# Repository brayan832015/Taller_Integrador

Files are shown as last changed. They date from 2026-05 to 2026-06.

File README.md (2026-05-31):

# EL5610 Integrative Workshop  
## Siwa Microcontroller Test and Interconnection Platform

This repository contains the development of the project for the **EL5610 Integrative Workshop** course at the School of Electronic Engineering, Instituto Tecnológico de Costa Rica.

The project consists of designing and developing a **test and interconnection platform for the Siwa microcontroller**, including schematic design, PCB layout, fabrication preparation, assembly, validation, and technical documentation.

## Development Methodology

This project is managed using the **Scrum Agile methodology**.

### Workflow includes:

- Product Backlog definition using GitHub Issues  
- Sprint planning and task prioritization  
- Iterative development cycles (Sprints)  
- Code/design reviews  
- Continuous progress tracking through GitHub Projects  

Version control is handled through feature branches and structured merges into the main branch.

---

## Repository Structure

```
/docs            → Technical documentation: Components datasheet and reports  
/pcb             → Schematic and PCB layout files  
```

---

## Roles and Responsibilities

### Brayan Barquero Madrigal – Project Owner
- Define and prioritize tasks in the Product Backlog.
- Ensure the board is properly updated (tasks moved to the correct columns).
- Review Pull Requests and approve or request changes.
- Ensure deliverables meet the acceptance criteria before moving them to **Done**.
- Take tasks from the Sprint Backlog and contribute technically to the project.
- Work on dedicated feature branches.
  
### Jeffrey Salas Quiel – Scrum Master
- Decide what enters each sprint.
- Lead the Daily Stand-Up (DSU) meetings.
- Identify blockers and help resolve them.
- Verify that each task has a clear description and an assigned responsible member.
- Take tasks from the Sprint Backlog and contribute technically to the project.
- Work on dedicated feature branches and create Pull Requests when tasks are completed.

### Priscilla Campos Zamora & Fiorela Chavarria Castrillo – Team Members
- Take tasks from the Sprint Backlog and move them to **In Progress**.
- Work on dedicated feature branches.
- Make clear commits and create a Pull Request when finished.
- Move tasks to **Review/Testing**, and then to **Done** once approved.
- Report blockers during meetings.

---

## Workflow

Product Backlog → Sprint Backlog → In Progress → Review/Testing → Done

---

## Tools & Technologies

- PCB CAD software (Altium Designer)  
- GitHub and Altium 365 for version control  
- Agile Scrum methodology  
- Laboratory validation equipment

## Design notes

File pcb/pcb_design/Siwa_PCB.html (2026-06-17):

Altium customize

# Board Information Report

Date: | | 6/15/2026
Time: | | 3:58:45 PM
Elapsed Time: | | 00:00:00
Filename: | | C:\Users\fchav\OneDrive - Estudiantes ITCR\SEMESTRE I 2026\TALLER INTEGRADOR\GITHUB\Taller_Integrador\pcb\pcb_design\Siwa_PCB.PcbDoc
Units: | | mmmils

## Contents

Contents

Board Specification

General

Routing

Routing Information

Layer Information

Layer Information

Drill Pairs

Copper Area

Copper Area

Board Holes

Non-Plated Hole Size

Plated Hole Size

Board Slots

Non-Plated Slot Size

Plated Slot Size

Board Square Holes

Non-Plated Square Hole Size

Plated Square Hole Size

Other

Top Layer Annular Ring Size

Mid Layer Annular Ring Size

Bottom Layer Annular Ring Size

Pad Solder Mask

Pad Paste Mask

Pad Pwr/Gnd Expansion

Pad Relief Conductor Width

Pad Relief Air Gap

Pad Relief Entries

Via Solder Mask

Via Pwr/Gnd Expansion

Track Width

Arc Line Width

Arc Radius

Arc Degrees

Text Height

Text Width

Net Track Width

Net Via Size

## Board Specification

General
Board Size | 120mm x 90.0001mm
Components on board | 68

Back to top

## Routing

Routing Information
Routing completion | 100.00%
Connections | 215
Connections routed | 215
Connections remaining | 0

Back to top

## Layer Information

Layer | Arcs | Pads | Vias | Tracks | Texts | Fills | Regions | ComponentBodies
Top Layer | 0 | 177 | 0 | 627 | 0 | 0 | 174 | 0
Bottom Layer | 0 | 0 | 0 | 163 | 0 | 0 | 71 | 0
Mechanical 1 | 0 | 0 | 0 | 0 | 1 | 0 | 0 | 0
Top 3D Body | 0 | 0 | 0 | 100 | 0 | 8 | 0 | 33
Top Courtyard | 0 | 0 | 0 | 132 | 0 | 0 | 0 | 0
Top Component Outline | 0 | 0 | 0 | 32 | 0 | 8 | 0 | 0
Top Assembly | 0 | 0 | 0 | 100 | 17 | 8 | 0 | 7
Bottom Component Outline | 0 | 0 | 0 | 0 | 0 | 0 | 0 | 0
Border | 0 | 0 | 0 | 4 | 0 | 0 | 0 | 0
Top Designator | 0 | 0 | 0 | 0 | 16 | 0 | 0 | 0
Bottom Designator | 0 | 0 | 0 | 0 | 0 | 0 | 0 | 0
Mechanical 13 | 0 | 0 | 0 | 88 | 0 | 0 | 0 | 62
Mechanical 15 | 0 | 0 | 0 | 171 | 0 | 0 | 0 | 0
Top Component Center | 0 | 0 | 0 | 66 | 0 | 0 | 0 | 0
Bottom Assembly | 0 | 0 | 0 | 32 | 0 | 0 | 0 | 0
Bottom Courtyard | 0 | 0 | 0 | 0 | 0 | 0 | 0 | 0
Bottom 3D Body | 0 | 0 | 0 | 0 | 0 | 0 | 0 | 0
Bottom Component Center | 0 | 0 | 0 | 0 | 0 | 0 | 0 | 0
Multi-Layer | 0 | 140 | 67 | 0 | 0 | 0 | 1 | 0
Top Paste | 0 | 0 | 0 | 0 | 0 | 0 | 0 | 0
Top Overlay | 12 | 0 | 0 | 142 | 137 | 16 | 0 | 0
Top Solder | 0 | 0 | 0 | 4 | 0 | 0 | 0 | 0
Bottom Solder | 0 | 0 | 0 | 4 | 0 | 0 | 0 | 0
Bottom Overlay | 0 | 0 | 0 | 0 | 0 | 0 | 0 | 0
Bottom Paste | 0 | 0 | 0 | 0 | 0 | 0 | 0 | 0
Drill Guide | 0 | 0 | 0 | 0 | 0 | 0 | 0 | 0
Keep-Out Layer | 0 | 0 | 0 | 0 | 0 | 0 | 0 | 0
Drill Drawing | 0 | 0 | 0 | 0 | 0 | 0 | 0 | 0
Total | 12 | 317 | 67 | 1665 | 171 | 40 | 246 | 102

Back to top

Drill Pairs | Vias
Top Layer - Bottom Layer | 67
Total | 67

Back to top

## Copper Area

Layer | Sq.In. | Sq.MM. | Percent of layer
Top Layer | 13.29 | 8573.926 | 79%
Bottom Layer | 14.675 | 9467.463 | 88%
Total | 27.965 | 18041.389

Back to top

## Board Holes

Non-Plated Hole Size | Pads | Vias
0mm | 46 | 0
Total | 46 | 0

Back to top

Plated Hole Size | Pads | Vias
0mm | 131 | 0
0.3mm | 0 | 67
1mm | 12 | 0
1.02mm | 32 | 0
1.1mm | 96 | 0
Total | 271 | 67

Back to top

## Board Slots

Non-Plated Slot Size / Length | Pads
Total | 0

Back to top

Plated Slot Size / Length | Pads
Total | 0

Back to top

## Board Square Holes

Non-Plated Square Hole Size | Pads
Total | 0

Back to top

Plated Square Hole Size | Pads
Total | 0

Back to top

## Other

Top Layer Annular Ring Size | Count
0.335mm | 67
0.5mm | 96
0.55mm | 8
0.78mm | 32
0.9mm | 4
Total | 207

Back to top

Mid Layer Annular Ring Size | Count
0.335mm | 67
0.5mm | 96
0.55mm | 8
0.78mm | 32
0.9mm | 4
Total | 207

Back to top

Bottom Layer Annular Ring Size | Count
0.335mm | 67
0.5mm | 96
0.55mm | 8
0.78mm | 32
0.9mm | 4
Total | 207

Back to top

Pad Solder Mask | Count
0mm | 281
0.1016mm | 4
0.5mm | 32
Total | 317

Back to top

Pad Paste Mask | Count
0mm | 317
Total | 317

Back to top

Pad Pwr/Gnd Expansion | Count
0.4mm | 317
Total | 317

Back to top

Pad Relief Conductor Width | Count
0.254mm | 317
Total | 317

Back to top

Pad Relief Air Gap | Count
0.254mm | 317
Total | 317

Back to top

Pad Relief Entries | Count
4 | 317
Total | 317

Back to top

Via Solder Mask | Count
0mm | 67
Total | 67

Back to top

Via Pwr/Gnd Expansion | Count
0.4mm | 67
Total | 67

Back to top

Track Width | Count
0.05mm | 196
0.1mm | 321
0.12mm | 20
0.2mm | 326
0.3mm | 430
0.4mm | 223
0.45mm | 46
0.5mm | 91
3mm | 12
Total | 1665

Back to top

Arc Line Width | Count
0.1mm | 2
0.25mm | 10
Total | 12

Back to top

Arc Radius | Count
0.05mm | 2
0.125mm | 10
Total | 12

Back to top

Arc Degrees | Count
180 | 2
360 | 10
Total | 12

Back to top

Text Height | Count
0.3mm | 1
1mm | 43
1.5mm | 59
1.524mm | 68
Total | 171

Back to top

Text Width | Count
0.05mm | 1
0.1mm | 33
0.254mm | 137
Total | 171

Back to top

Net Track Width | Count
0.3mm | 95
Total | 95

Back to top

Net Via Size | Count
1mm | 95
Total | 95

Back to top

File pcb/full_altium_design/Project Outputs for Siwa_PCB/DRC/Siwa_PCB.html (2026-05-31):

Altium

# Design Rule Verification Report

Date: | | 5/8/2026
Time: | | 11:53:02 PM
Elapsed Time: | | 00:00:05
Filename: | | C:\Users\Public\Documents\Altium\Siwa_PCB_1\Siwa_PCB.PcbDoc

Warnings: | | 0
Rule Violations: | | 0

## Summary

Warnings | Count
Total | 0

Rule Violations | Count
Clearance Constraint (Gap=0.254mm) (All),(All) | 0
Short-Circuit Constraint (Allowed=No) (All),(All) | 0
Un-Routed Net Constraint ( (All) ) | 0
Modified Polygon (Allow modified: No), (Allow shelved: No) | 0
Width Constraint (Min=0.3mm) (Max=0.4mm) (Preferred=0.4mm) (All) | 0
Width Constraint (Min=0.3mm) (Max=0.5mm) (Preferred=0.5mm) (InNetClass('Power')) | 0
Routing Topology Rule(Topology=Shortest) (All) | 0
Routing Layers(All) | 0
Routing Via (MinHoleWidth=0.3mm) (MaxHoleWidth=0.72mm) (PreferredHoleWidth=0.6mm) (MinWidth=0.63mm) (MaxWidth=1.28mm) (PreferedWidth=1mm) (All) | 0
Differential Pairs Uncoupled Length using the Gap Constraints (Min=0.254mm) (Max=0.254mm) (Prefered=0.254mm) and Width Constraints (Min=0.381mm) (Max=0.381mm) (Prefered=0.381mm) (All) | 0
Power Plane Connect Rule(Relief Connect )(Expansion=0.508mm) (Conductor Width=0.254mm) (Air Gap=0.254mm) (Entries=4) (All) | 0
Hole Size Constraint (Min=0.025mm) (Max=2.54mm) (All) | 0
Pads and Vias to follow the Drill pairs settings | 0
Hole To Hole Clearance (Gap=0.254mm) (All),(All) | 0
Minimum Solder Mask Sliver (Gap=0.2mm) (All),(All) | 0
Silk To Solder Mask (Clearance=0.15mm) (IsPad),(All) | 0
Silk to Silk (Clearance=0.254mm) (All),(All) | 0
Net Antennae (Tolerance=0mm) (All) | 0
Component Clearance Constraint ( Horizontal Gap = 0.254mm, Vertical Gap = 0.254mm ) (All),(All) | 0
Height Constraint (Min=0mm) (Max=25.4mm) (Prefered=12.7mm) (All) | 0
Supply Net(s)(InNet('UART_TX')) | 0
Supply Net(s)(InNet('1.8V')) | 0
Supply Net(s)(InNet('POC_CONTROL')) | 0
Supply Net(s)(InNet('GPIO_PAD_6_OUT')) | 0
Supply Net(s)(InNet('GPIO_PAD_7')) | 0
Supply Net(s)(InNet('MAIP')) | 0
Supply Net(s)(InNet('GPIO_PAD_0_OUT')) | 0
Supply Net(s)(InNet('GPIO_LED_0')) | 0
Supply Net(s)(InNet('GPIO_PAD_4_OUT')) | 0
Supply Net(s)(InNet('GPIO_PAD_2')) | 0
Supply Net(s)(InNet('GPIO_LED_1')) | 0
Supply Net(s)(InNet('GPIO_PAD_7_OUT')) | 0
Supply Net(s)(InNet('H_LED_4')) | 0
Supply Net(s)(InNet('GPIO_PAD_4')) | 0
Supply Net(s)(InNet('GPIO_PAD_3')) | 0
Supply Net(s)(InNet('1V')) | 0
Supply Net(s)(InNet('GPIO_PAD_5_OUT')) | 0
Supply Net(s)(InNet('GPIO_PAD_1')) | 0
Supply Net(s)(InNet('GPIO_LED_3')) | 0
Supply Net(s)(InNet('GPIO_PAD_1_OUT')) | 0
Supply Net(s)(InNet('GPIO_LED_6')) | 0
Supply Net(s)(InNet('GND')) | 0
Supply Net(s)(InNet('UART_RX')) | 0
Supply Net(s)(InNet('GPIO_PAD_5')) | 0
Supply Net(s)(InNet('GPIO_LED_7')) | 0
Supply Net(s)(InNet('GPIO_PAD_6')) | 0
Supply Net(s)(InNet('GPIO_PAD_3_OUT')) | 0
Supply Net(s)(InNet('GPIO_LED_5')) | 0
Supply Net(s)(InNet('H_LED_6')) | 0
Supply Net(s)(InNet('3V')) | 0
Supply Net(s)(InNet('GPIO_PAD_2_OUT')) | 0
Supply Net(s)(InNet('GPIO_LED_2')) | 0
Supply Net(s)(InNet('GPIO_LED_4')) | 0
Supply Net(s)(InNet('H_LED_7')) | 0
Supply Net(s)(InNet('H_LED_5')) | 0
Supply Net(s)(InNet('GPIO_PAD_0')) | 0
Total | 0

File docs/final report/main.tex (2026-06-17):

\documentclass[journal,trans]{IEEEtran}
\usepackage[utf8]{inputenc}
\usepackage[spanish,es-tabla]{babel}
\usepackage[bottom]{footmisc}
\usepackage[hidelinks]{hyperref}
\usepackage[parfill]{parskip}
\usepackage[]{graphicx}
\usepackage[]{float}
\usepackage[]{caption}
\usepackage[]{multirow}
\usepackage[]{multicol}
\usepackage[]{siunitx}
\usepackage[]{tabularx}
\usepackage[]{amsmath}
\usepackage[]{textcomp, gensymb}
\usepackage[]{array}
\spanishdecimal{.}
\graphicspath{{Figures/}}
\hyphenation{op-tical net-works semi-conduc-tor}
\raggedbottom

\begin{document}

%\\\\\\\\\\\\\\\\\\\\\\\\\\\\\\\\\\\\\\\\\\\\\\
%Título
%\\\\\\\\\\\\\\\\\\\\\\\\\\\\\\\\\\\\\\\\\\\\\\

\title{Diseño, implementación y validación de una tarjeta de pruebas para el microcontrolador Siwa}

\renewcommand\IEEEkeywordsname{Palabras clave}

\author{ \rule{\linewidth}{0.5pt}\vspace{10pt}
\IEEEauthorblockN{Instituto Tecnológico de Costa Rica \\Escuela de Ingeniería Electrónica \\EL5610 Taller Integrador \\Prof. Luis Carlos Rosales Alpízar\\Brayan Barquero Madrigal$^{1}$, Yailyn Priscilla Campos Zamora$^{2}$, Fiorela Chavarría Castrillo$^{3}$, Jeffrey Salas Quiel$^{4}$\\brabarmad@estudiantec.cr$^{1}$, camposzamora@estudiantec.cr$^{2}$}, fchavarria@estudiantec.cr$^{3}$, jeffrey080203@estudiantec.cr$^{4}$}

\markboth{}%
{Shell \MakeLowercase{\textit{et al.}}: Bare Demo of IEEEtran.cls for Journals}

%\\\\\\\\\\\\\\\\\\\\\\\\\\\\\\\\\\\\\\\\\\\\\\
%Resumen y Palabras Clave
%\\\\\\\\\\\\\\\\\\\\\\\\\\\\\\\\\\\\\\\\\\\\\\

\IEEEtitleabstractindextext{%

\begin{abstract}
	Este trabajo presenta el diseño, fabricación y validación de una tarjeta de pruebas para la plataforma Siwa, desarrollada con el propósito de proporcionar interfaces de alimentación, comunicación y expansión para evaluar el funcionamiento del microcontrolador y sus periféricos asociados. El desarrollo incluyó la selección de componentes, elaboración de bibliotecas, diseño del esquemático y generación del \textit{layout} de la PCB utilizando Altium Designer. La tarjeta fue implementada en dos capas de cobre, incorporando polígonos para GND y alimentación, vías para transiciones entre capas y ajustes posteriores en el borde mecánico, pasando de una geometría inicial de \(10\,\text{cm} \times 10\,\text{cm}\) a una versión final de \(12\,\text{cm} \times 9\,\text{cm}\). La validación se realizó mediante pruebas de continuidad, mediciones eléctricas y ejecución del \textit{Design Rule Check} (DRC), permitiendo verificar el comportamiento de distintos módulos e identificar fallas asociadas a conexiones y ensamblaje. Los resultados obtenidos evidenciaron la utilidad de los procesos de verificación durante el desarrollo de hardware, así como la necesidad de adaptar el diseño ante cambios de requerimientos y restricciones de fabricación.
\end{abstract}

\begin{IEEEkeywords}
Altium Designer, DRC, PCB, planos de tierra, Siwa.
\end{IEEEkeywords}}

\maketitle
\IEEEdisplaynontitleabstractindextext
\IEEEpeerreviewmaketitle

\setlength{\parindent}{1.27cm}
\setlength{\parskip}{0cm}

%\\\\\\\\\\\\\\\\\\\\\\\\\\\\\\\\\\\\\\\\\\\\\\
%Introducción
%\\\\\\\\\\\\\\\\\\\\\\\\\\\\\\\\\\\\\\\\\\\\\\

\section{Introducción}
%Explicar el contexto y los alcances del proyecto.
El desarrollo y la validación de circuitos integrados requieren plataformas físicas que permitan proporcionar las condiciones eléctricas necesarias para su operación, acceder a sus interfaces y observar su comportamiento mediante instrumentos de medición. Estas plataformas resultan especialmente importantes durante las etapas de caracterización de un dispositivo, ya que facilitan la conexión de fuentes de alimentación, señales de reloj, memorias, periféricos y puntos de prueba alrededor del circuito integrado.\\

En este contexto, el microcontrolador SIWA es un dispositivo de uso general desarrollado en el DCILab del Instituto Tecnológico de Costa Rica y basado en la arquitectura abierta RISC-V 32-I. Posee una arquitectura multiciclo y fabricada en tecnología CMOS. Para utilizar el microcontrolador fuera de su encapsulado y comprobar experimentalmente sus funciones, se requiere una plataforma de interconexión capaz de suministrar sus diferentes tensiones de alimentación, proporcionar una señal de reloj estable y facilitar el acceso a sus señales de entrada y salida.\\

El presente proyecto consistió en el diseño, implementación y validación de una tarjeta de circuito impreso destinada a funcionar como plataforma de pruebas para el microcontrolador SIWA. La tarjeta fue concebida para integrar los circuitos auxiliares necesarios para su operación, entre ellos reguladores de tensión, una fuente de reloj, interfaces para memoria externa, indicadores LED, una conexión para pantalla OLED, adaptación de niveles lógicos y conectores destinados al acceso, monitoreo y prueba de las señales. El trabajo abarcó las distintas etapas de desarrollo de un sistema electrónico, desde la interpretación de las especificaciones y el diseño del circuito hasta la fabricación, el ensamblaje y la evaluación experimental del PCB.\\

El desarrollo se organizó mediante una metodología ágil, utilizando herramientas de planificación, seguimiento de tareas y control de versiones para coordinar el trabajo colaborativo del equipo.

\subsection{Alcances}
El alcance inicialmente establecido comprendió la selección de componentes, la elaboración del esquemático, el diseño del layout de la PCB y su verificación previa a la fabricación mediante reglas de diseño y criterios de diseño para manufactura. También incluyó la generación de los archivos necesarios para la fabricación, el ensamblaje de componentes de montaje superficial y \textit{through-hole}, y la inspección eléctrica de la tarjeta fabricada.\\

Posteriormente, el proyecto contempló la validación del sistema de alimentación, la señal de reloj, las conexiones entre bloques y las interfaces asociadas al microcontrolador. Asimismo, se planteó la carga de un programa para comprobar el funcionamiento de SIWA y la caracterización de su consumo de potencia. Debido a las limitaciones encontradas durante la fabricación y el ensamblaje, el alcance experimental se ajustó a la validación individual de bloques y al diagnóstico de las fallas presentes en la tarjeta. También se documentaron la planificación del proyecto, la asignación de responsabilidades, el seguimiento de las tareas y el trabajo colaborativo realizado durante el diseño.

%\\\\\\\\\\\\\\\\\\\\\\\\\\\\\\\\\\\\\\\\\\\\\\
%Proceso de diseño
%\\\\\\\\\\\\\\\\\\\\\\\\\\\\\\\\\\\\\\\\\\\\\\

\section{Proceso de diseño}

%Explicar los pasos que se siguieron para diseñar la PCB.

El diseño de la tarjeta de pruebas para el microcontrolador Siwa se desarrolló mediante un proceso iterativo que abarcó la elaboración del esquemático, la implementación del \textit{layout} de la PCB y la verificación del diseño mediante reglas eléctricas y mecánicas. El flujo de trabajo se realizó utilizando \textit{Altium Designer}, permitiendo mantener la consistencia entre el esquemático, las bibliotecas y el diseño físico de la tarjeta.

\subsection{Preparación y selección de componentes}

La primera etapa consistió en la búsqueda y selección de los componentes requeridos por la plataforma de pruebas de Siwa. Para ello se consultaron las hojas de datos de cada dispositivo con el fin de verificar parámetros eléctricos, encapsulados, distribución de pines y requerimientos de alimentación. Este procedimiento permitió asegurar la compatibilidad entre los distintos bloques funcionales y evitar discrepancias entre el diseño lógico y el físico.

Durante esta fase se desarrollaron las bibliotecas necesarias para el proyecto, incluyendo la creación de símbolos esquemáticos y \textit{footprints} para los distintos componentes utilizados, desde elementos discretos, como capacitores y resistencias, hasta conectores y \textit{headers}. La construcción de estas bibliotecas requirió verificar cuidadosamente la correspondencia entre la numeración de pines, los encapsulados físicos y las dimensiones mecánicas especificadas en las hojas de datos de cada dispositivo \cite{ipc7351}.

\subsection{Desarrollo del esquemático}

Una vez definidos los componentes, se procedió a elaborar el esquemático del sistema. Los distintos bloques funcionales fueron organizados de acuerdo con su función dentro de la plataforma, incluyendo el sistema de alimentación, los reguladores de voltaje, el oscilador, los \textit{buffers}, los \textit{level shifters}, los conectores de expansión y las interfaces hacia el microcontrolador Siwa.

\begin{figure}[H]
	\centering
	
	\caption{Esquemático general de la tarjeta de pruebas para la plataforma Siwa.}
	\label{fig:esquematico_general}
\end{figure}

Durante la elaboración del esquemático se verificó la conectividad eléctrica entre nodos y se asignaron nombres a las redes de alimentación y señal. El uso de nombres de red facilita el seguimiento de conexiones complejas y reduce la probabilidad de errores durante la transferencia del diseño al PCB \cite{altium_nets}.

Posteriormente, se asignaron los \textit{footprints} correspondientes a cada componente y se verificó nuevamente la correspondencia entre símbolos y encapsulados. Antes de transferir el diseño al PCB se comprobó la integridad del esquemático mediante las herramientas de compilación y verificación eléctrica disponibles en el entorno de diseño \cite{altium_schematic}.

\begin{figure}[H]
	\centering
	
	\caption{Bloque de alimentación y regulación de voltaje de la tarjeta.}
	\label{fig:sistema_alimentacion}
\end{figure}

\begin{figure}[H]
	\centering
	
	\caption{Interfaz principal del microcontrolador Siwa, memoria externa y \textit{header} de expansión.}
	\label{fig:interfaz_siwa}
\end{figure}

\begin{figure}[H]
	\centering
	
	\caption{Circuitos de reloj, reinicio y acondicionamiento de señales asociados al sistema.}
	\label{fig:oscilador_reset}
\end{figure}

\begin{figure}[H]
	\centering
	
	\caption{Bloques de conversión de nivel lógico y conexión de periféricos externos.}
	\label{fig:level_shifters}
\end{figure}

\begin{figure}[H]
	\centering
	
	\caption{Banco de indicadores LED asociados a señales GPIO.}
	\label{fig:indicadores_led}
\end{figure}

\subsection{Primera versión del PCB}

Con el esquemático validado se generó el documento de PCB mediante el proceso de sincronización entre esquemático y tarjeta. Este procedimiento permite transferir automáticamente componentes, redes y restricciones hacia el \textit{layout} físico \cite{altium_pcb}.

Inicialmente se definió una geometría de tarjeta de \(10\,\text{cm} \times 10\,\text{cm}\), estableciendo el borde mecánico y el área disponible para el posicionamiento de componentes. La ubicación de los elementos se realizó considerando restricciones mecánicas, acceso a conectores y facilidad de ruteo.

Los conectores externos y \textit{headers} fueron colocados en posiciones accesibles desde el borde de la tarjeta, mientras que los circuitos asociados al microcontrolador Siwa fueron agrupados en regiones cercanas a sus interfaces correspondientes. Esta organización facilitó la interconexión entre bloques funcionales y el aprovechamiento del área disponible en la PCB.

Una vez completado el posicionamiento inicial, se definieron las reglas y \textit{constraints} del diseño. Estas restricciones incluyeron separación eléctrica, anchos de pista, dimensiones de vías, capas habilitadas para ruteo, conexión a polígonos de cobre y ubicación de elementos de \textit{silkscreen}. Los valores se establecieron considerando las recomendaciones de fabricación disponibles para el proyecto y los requerimientos eléctricos de las redes. En el diseño se configuró una separación general de \(0.25\,\text{mm}\), pistas de señal con ancho mínimo de \(0.3\,\text{mm}\) y ancho preferido de \(0.4\,\text{mm}\), mientras que las redes de alimentación se agruparon en una clase \textit{Power} con ancho mínimo de \(0.45\,\text{mm}\) y preferido de \(0.5\,\text{mm}\) \cite{ipc2221}.

Con base en estas restricciones, las pistas de señal se diseñaron principalmente con anchos de \(0.3\,\text{mm}\), mientras que las redes de alimentación utilizaron anchos mayores para favorecer la conducción de corriente cuando el espacio disponible lo permitió. Asimismo, los polígonos de cobre se configuraron con una separación de \(0.4\,\text{mm}\), con el fin de mantener el aislamiento entre distintas redes eléctricas y evitar interferencias entre regiones de cobre adyacentes.

El ruteo se implementó sobre una PCB de dos capas, utilizando tanto la capa Top como la Bottom para distribuir las conexiones eléctricas del sistema. Esta configuración resultó suficiente para el número de componentes y conexiones del sistema, permitiendo completar el diseño sin recurrir a capas internas adicionales. Se implementaron polígonos de GND en ambas capas con el fin de proporcionar un plano de referencia continuo y facilitar el retorno de corriente. Adicionalmente, algunas redes de alimentación, como \(1\,\mathrm{V}\), \(1.8\,\mathrm{V}\), \(3\,\mathrm{V}\) y la entrada de \(5\,\mathrm{V}\), se distribuyeron mediante polígonos locales y pistas dedicadas. Los polígonos se configuraron con una separación de \(0.4\,\text{mm}\) para mantener aislamiento eléctrico entre redes adyacentes \cite{johnson2003}.

Durante el enrutamiento se procuró mantener trayectorias directas entre bloques relacionados, utilizando cambios de capa cuando el cruce entre señales o la congestión local lo requería. Para ello se emplearon 67 vías metalizadas, las cuales permitieron conectar la capa superior con la inferior y completar las 215 conexiones eléctricas definidas en el esquemático. De esta manera, el uso de vías se aplicó como una solución puntual para resolver cruces y mantener la continuidad del ruteo en una tarjeta de dos capas.

Para estas transiciones se seleccionaron vías con un orificio de \(0.3\,\text{mm}\) y un diámetro total cercano a \(1\,\text{mm}\). Estas dimensiones se ajustan a las recomendaciones de fabricación disponibles para el proyecto, donde se indicaba un orificio mínimo de \(0.3\,\text{mm}\) para vías \textit{through-hole}. La selección de este tamaño permitió mantener compatibilidad con el proceso de perforación y metalización, sin reducir excesivamente el anillo anular de cobre alrededor del orificio \cite{ipc2221}.

Durante esta etapa también se ajustaron propiedades relacionadas con \textit{thermal reliefs}. En determinadas conexiones se removieron estos elementos con el fin de establecer una unión directa al plano de cobre. La utilización o eliminación de \textit{thermal reliefs} depende de requerimientos eléctricos y de ensamblaje, ya que estos modifican la transferencia de calor durante el proceso de soldadura y la conexión eléctrica con los polígonos de cobre \cite{ipc2221}.

Finalizado el ruteo inicial se ejecutó el \textit{Design Rule Check} (DRC) para verificar el cumplimiento de las restricciones eléctricas y mecánicas del diseño. Las violaciones detectadas se corrigieron ajustando anchos de pistas en redes de alimentación, incrementando la separación entre conductores cuando existían conflictos de \textit{clearance}, reubicando vías para evitar interferencias con pads o polígonos, y modificando textos o elementos de serigrafía que invadían zonas de máscara de soldadura. Después de cada conjunto de cambios se volvió a ejecutar el DRC, con el fin de comprobar que las correcciones no introdujeran nuevas violaciones.

\subsection{Modificación del diseño}

Posteriormente se realizó una modificación de las dimensiones de la tarjeta, pasando de \(10\,\text{cm} \times 10\,\text{cm}\) a \(12\,\text{cm} \times 9\,\text{cm}\), con el fin de ajustarse a los requerimientos establecidos para la versión final del PCB. Este cambio obligó a reorganizar parte del \textit{layout}, reposicionar los \textit{headers} inferiores y rehacer secciones del ruteo.

Tras completar las modificaciones se ejecutó nuevamente el DRC y se corrigieron las violaciones restantes hasta obtener un diseño libre de errores eléctricos y geométricos reportados por el sistema de verificación.

\begin{figure}[H]
	\centering
	
	\caption{Vista general del \textit{layout} final de la tarjeta de pruebas para el microcontrolador Siwa.}
	\label{fig:pcb_general}
\end{figure}

\subsection{Documentación de salida}

Una vez verificado el diseño, se generaron los archivos de fabricación requeridos para el proceso de manufactura. Entre ellos se incluyen los archivos Gerber, utilizados para describir la geometría de las capas del PCB, y los archivos de perforación o \textit{drill files}, empleados para especificar la ubicación y dimensiones de los orificios \cite{gerber_altium}.

La generación de estos documentos permite transferir la información del diseño hacia los procesos de fabricación sin modificar el proyecto original. No obstante, la exportación de dichos archivos constituye una etapa complementaria al diseño \cite{gerber_altium}..

%\\\\\\\\\\\\\\\\\\\\\\\\\\\\\\\\\\\\\\\\\\\\\\
%Proceso de fabricación
%\\\\\\\\\\\\\\\\\\\\\\\\\\\\\\\\\\\\\\\\\\\\\\

\section{Proceso de fabricación}

%Explicar los pasos de fabricación y los errores que se encontraron y las causas posibles.

\subsection{Perforado}
Una vez terminado el diseño en Altium, se exportan los archivos para la fabricación de la PCB. A partir de estos,
se realiza el perforado de la placa de cobre para obtener los orificios pasantes (\text{through-hole}) y las vías. En la figuras
 \ref{fig:drilling_1} y \ref{fig:drilling_2} se observan el plano de referencia para el perforado y la placa ya perforada, respectivamente. 

\begin{figure}[H]
    \centering
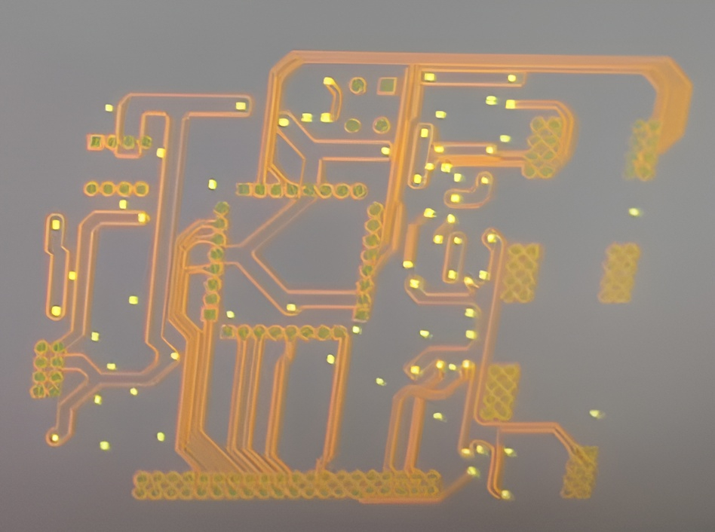
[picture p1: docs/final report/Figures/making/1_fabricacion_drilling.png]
    
    \caption{Plano de referencia para el perforado.}
    \label{fig:drilling_1}
\end{figure}

\begin{figure}[H]
    \centering
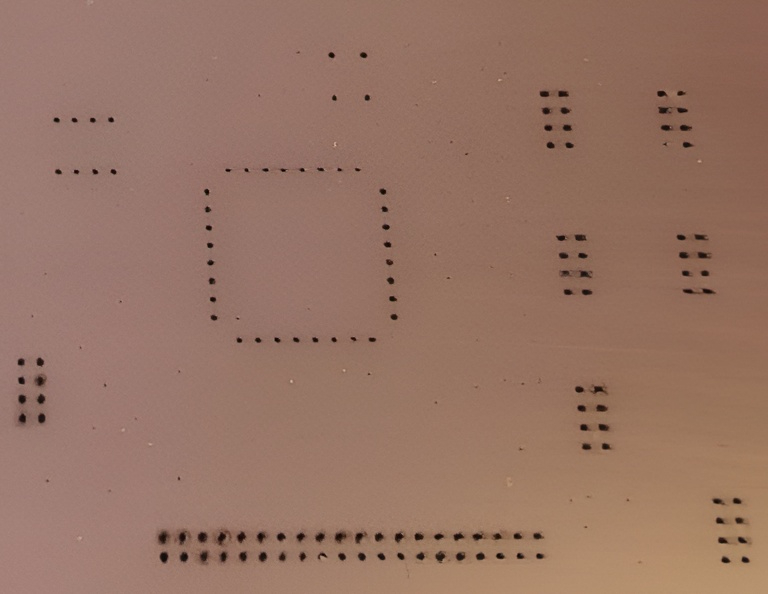
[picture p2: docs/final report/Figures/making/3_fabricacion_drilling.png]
    
    \caption{Placa perforada.}
    \label{fig:drilling_2}
\end{figure}

\subsection{Metalización de orificios}

Después del perforado, se realiza la metalización de los orificios para permitir la conexión eléctrica entre las capas de la PCB. 
Primero, se lava la placa perforada utilizando agua tibia con el fin de remover cualquier residuo. Luego, se realiza un baño en 
carbón activado, para que las paredes de los orificios queden eléctricamente conductoras, ya que despues del perforado, estas son
de material dieléctrico (figura \ref{fig:carbon_bath}). 

\begin{figure}[H]
    \centering
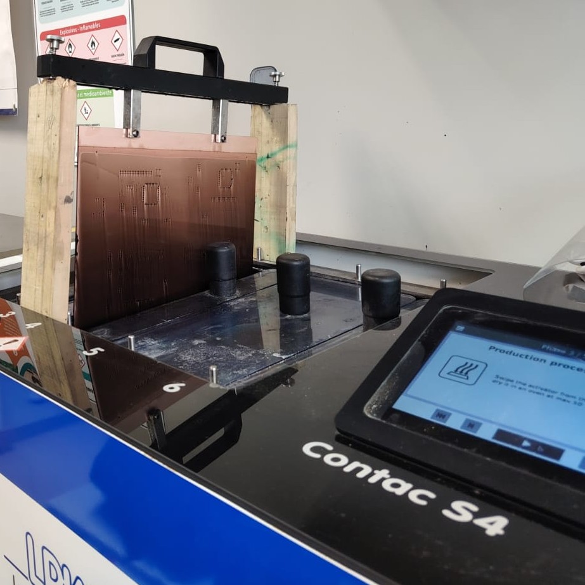
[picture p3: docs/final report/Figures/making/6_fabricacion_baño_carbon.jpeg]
    
    \caption{Baño en carbón activado para metalizar los orificios.}
    \label{fig:carbon_bath}
\end{figure}

Después de este proceso, se utiliza un horno para secar la placar y fijar
el carbón activado obteniendo el resultado mostrado en la figura \ref{fig:carbon_bath_result}.

\begin{figure}[H]
    \centering
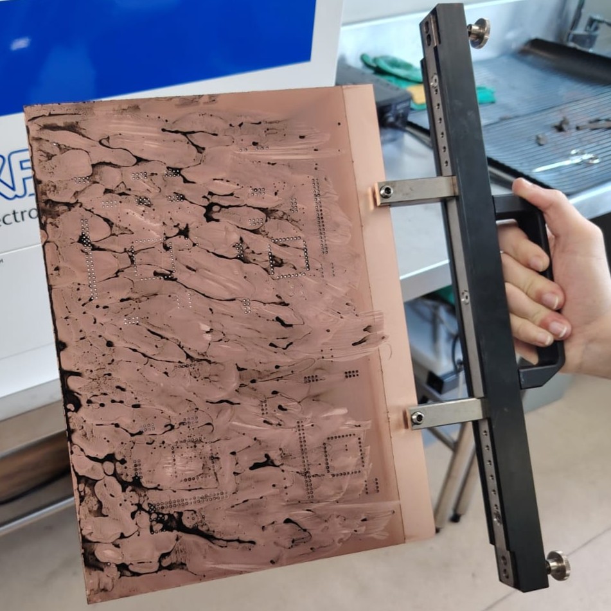
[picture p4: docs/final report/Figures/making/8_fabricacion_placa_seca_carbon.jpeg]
    
    \caption{Resultado después de secar la placa y fijar el carbón activado.}
    \label{fig:carbon_bath_result}
\end{figure}

A continuación, se realiza un baño en ácido sulfúrico para galvanizar los orificios, es decir, 
cubrirlos con una capa de metal (figura \ref{fig:acid_bath}).

\begin{figure}[H]
    \centering
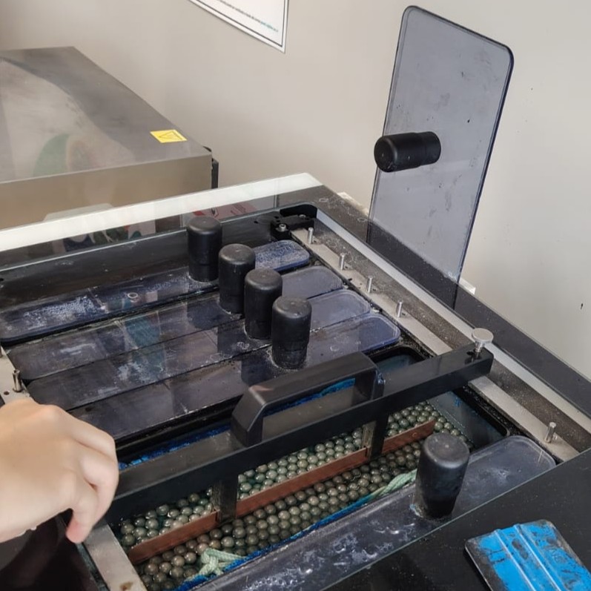
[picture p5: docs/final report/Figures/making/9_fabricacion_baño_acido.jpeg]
    
    \caption{Baño en ácido sulfúrico para galvanizar los orificios.}
    \label{fig:acid_bath}
\end{figure}

Después se limpia la placa con agua para obtener el resultado mostrado en la figura \ref{fig:acid_bath_result}.

\begin{figure}[H]
    \centering
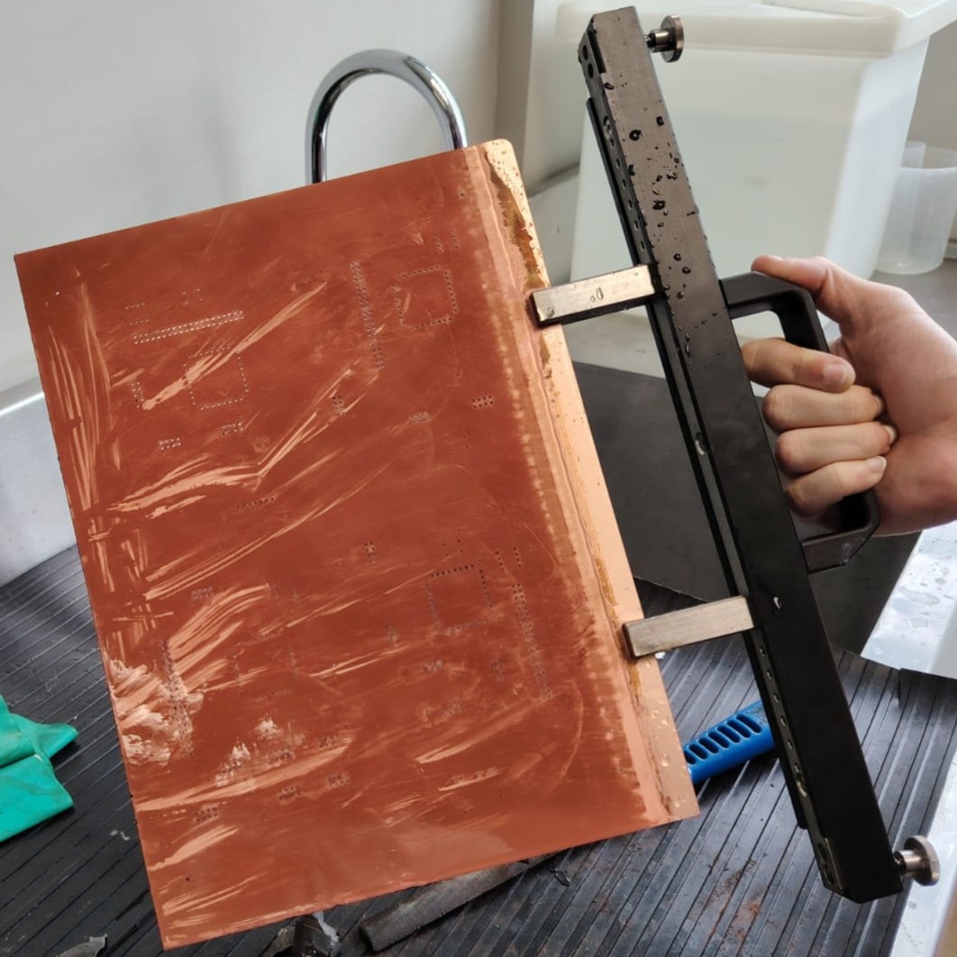
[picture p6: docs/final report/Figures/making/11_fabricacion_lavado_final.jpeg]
    
    \caption{Resultado después de del baño en ácido sulfúrico y de limpiar la placa con agua.}
    \label{fig:acid_bath_result}
\end{figure}

\subsection{Recubrimiento y curado}

Se parte de la placa perforada, sobre la que se aplica una fotorresina 
que se expone a luz UV a través del diseño del circuito. Las zonas no endurecidas se disuelven y 
el cobre expuesto se elimina químicamente, dejando solo las pistas. Luego se perforan los orificios,
se aplica la máscara de soldadura verde que protege el cobre y deja al descubierto solo los pads,
y finalmente se imprime la serigrafía blanca con las referencias de los componentes. El resultado es el
que se muestra en la figura \ref{fig:coating}.

\begin{figure}[H]
    \centering
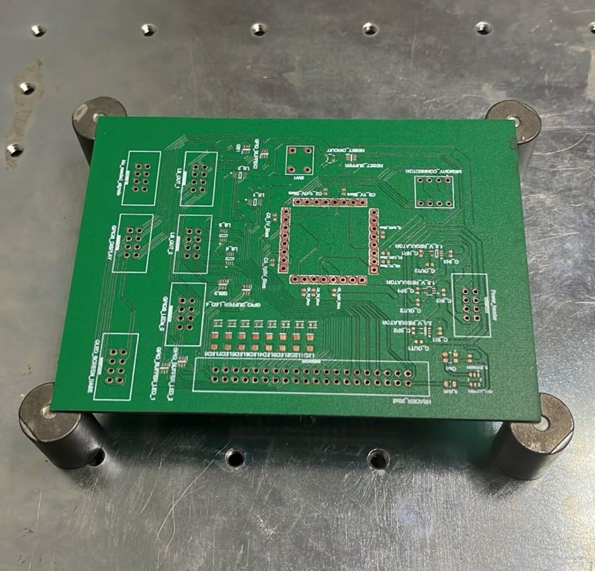
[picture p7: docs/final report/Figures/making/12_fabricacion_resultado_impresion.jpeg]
    
    \caption{Resultado después de aplicar la máscara de soldadura y la serigrafía.}
    \label{fig:coating}
\end{figure}

\subsection{Soldadura de montaje superficial}

Con ayuda de un \textit{stencil} se aplica manualmente la pasta de soldadura sobre los pads de la placa (ver figura \ref{fig:stencil}), 
luego se retira el \textit{stencil} (ver figuras \ref{fig:stencil_removed} y \ref{fig:stencil_removed2}).

\begin{figure}[H]
    \centering
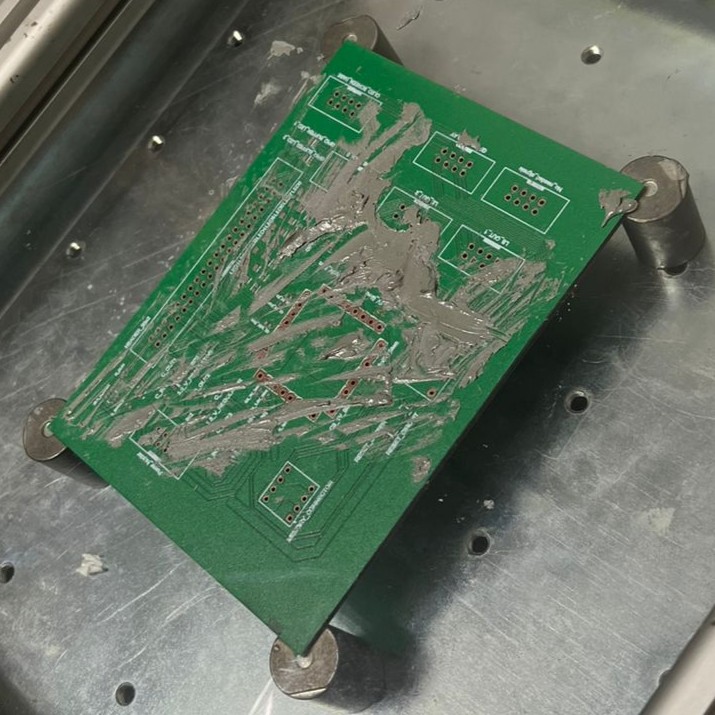
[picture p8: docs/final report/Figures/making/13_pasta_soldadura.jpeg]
    
    \caption{Aplicación de la pasta de soldadura usando un \textit{stencil}.}
    \label{fig:stencil}
\end{figure}

\begin{figure}[H]
    \centering
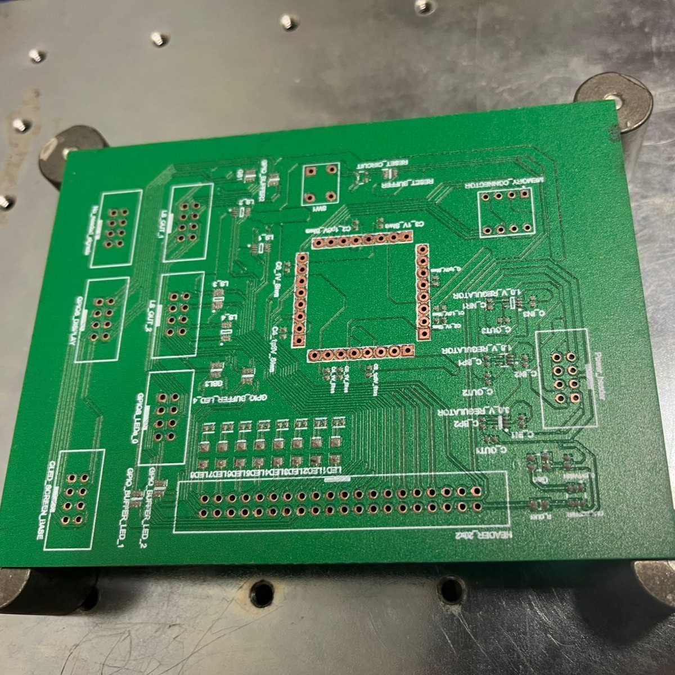
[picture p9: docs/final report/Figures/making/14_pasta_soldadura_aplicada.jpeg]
    
    \caption{Resultado después de retirar el \textit{stencil}.}
    \label{fig:stencil_removed}
\end{figure}

\begin{figure}[H]
    \centering
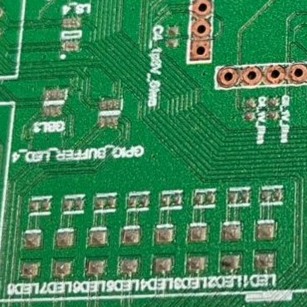
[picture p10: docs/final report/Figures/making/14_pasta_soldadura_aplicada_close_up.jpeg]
    
    \caption{Detalle del resultado después de retirar el \textit{stencil}.}
    \label{fig:stencil_removed2}
\end{figure}

Una vez que los pads están cubiertos con la pasta de soldadura, se colocan los componentes de montaje superficial
manualmente con ayuda de una máquina \textit{pick and place} (ver figuras \ref{fig:pick_and_place} y \ref{fig:pick_and_place_close_up}).

\begin{figure}[H]
    \centering
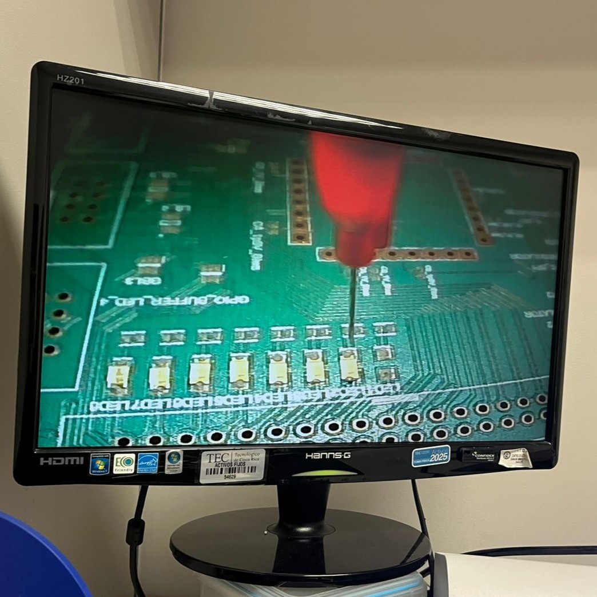
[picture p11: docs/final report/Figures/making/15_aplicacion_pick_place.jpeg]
    
    \caption{Colocación de los componentes de montaje superficial usando la máquina \textit{pick and place}.}
    \label{fig:pick_and_place}
\end{figure}

\begin{figure}[H]
    \centering
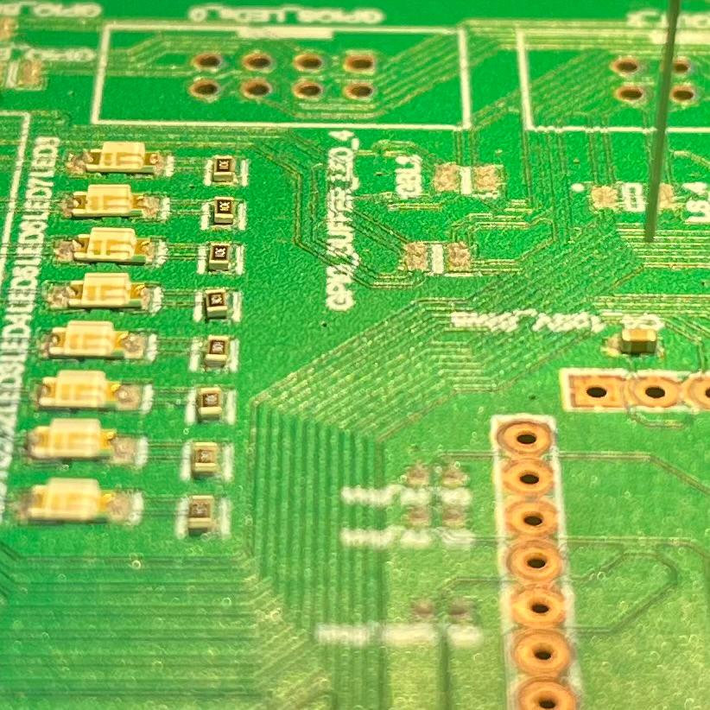
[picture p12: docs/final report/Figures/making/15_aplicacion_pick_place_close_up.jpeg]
    
    \caption{Detalle de la colocación de los componentes de montaje superficial usando la máquina \textit{pick and place}.}
    \label{fig:pick_and_place_close_up}
\end{figure}

Una vez que se han colocado todos los componentes de montaje superficial, se introduce la placa en un horno para fijar la soldadura (figura \ref{fig:horneado}). 

\begin{figure}[H]
    \centering
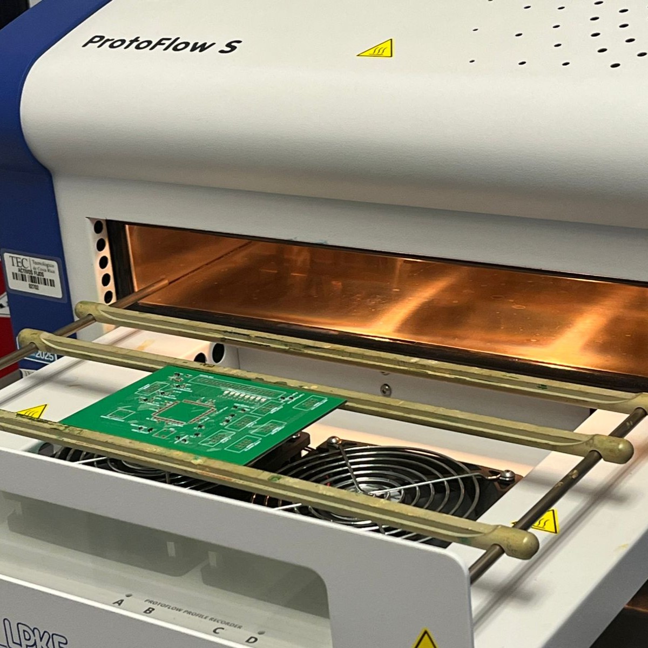
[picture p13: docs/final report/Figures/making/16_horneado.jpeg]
    
    \caption{Horneado de la placa para fijar la soldadura de los componentes de montaje superficial.}
    \label{fig:horneado}
\end{figure}

\subsection{Soldadura de componentes pasantes}

Después de fijar los componentes de montaje superficial, se procede a soldar los componentes pasantes manualmente 
con una estación de soldadura (figura \ref{fig:fabricacion_soldadura}), obteniendo el resultado mostrado en la figura \ref{fig:fabricacion_soldadura_resultado}.

\begin{figure}[H]
    \centering
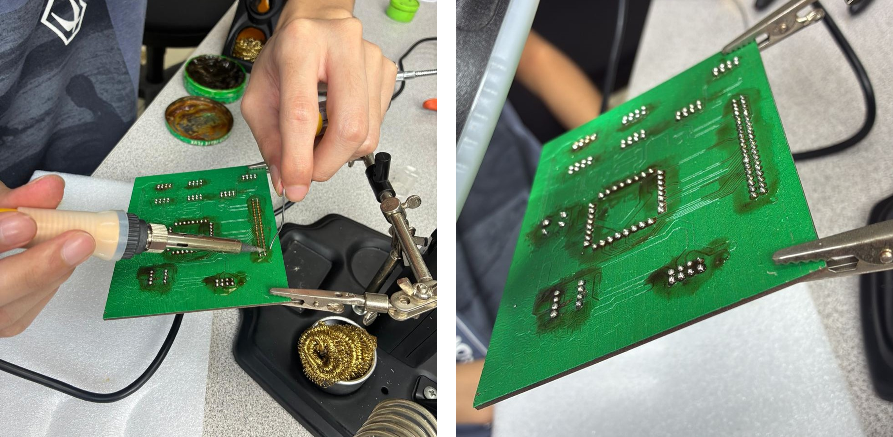
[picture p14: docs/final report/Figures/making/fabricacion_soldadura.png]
    
    \caption{Proceso de soldadura de los componentes pasantes.}
    \label{fig:fabricacion_soldadura}
\end{figure}

\begin{figure}[H]
    \centering
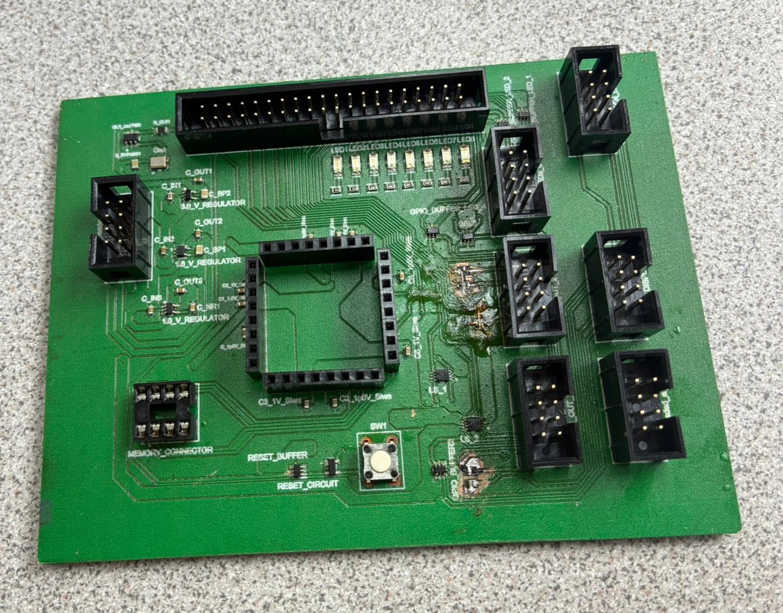
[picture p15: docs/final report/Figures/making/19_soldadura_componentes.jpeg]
    
    \caption{Resultado de la placa con los componentes pasantes soldados.}
    \label{fig:fabricacion_soldadura_resultado}
\end{figure}

%\\\\\\\\\\\\\\\\\\\\\\\\\\\\\\\\\\\\\\\\\\\\\\
%Proceso de validación
%\\\\\\\\\\\\\\\\\\\\\\\\\\\\\\\\\\\\\\\\\\\\\\

\section{Proceso de validación}

%¿Cómo se prueba la integridad de la tarjeta? Explicar el procedimiento seguido.

En esta sección se documenta el procedimiento sistemático de depuración y validación 
llevado a cabo sobre la tarjeta PCB fabricada para la plataforma de pruebas del
microcontrolador Siwa. El proceso siguió una lógica de diagnóstico estructurada, partiendo
de la identificación de los síntomas iniciales observados tras el ensamblaje, avanzando
hacia la verificación funcional de bloques
individuales, y concluyendo con un análisis de la evidencia experimental que
permite establecer la causa más probable de fallo. El objetivo central fue determinar si
los problemas observados correspondían a errores de diseño en el esquemático o en el
\textit{layout}, o bien a condiciones originadas durante el proceso de fabricación o ensamblaje.

%---------------------------------------------------------
\subsection{Cortocircuitos durante el ensamblaje}
%---------------------------------------------------------

Durante el proceso de ensamblaje de los componentes sobre la tarjeta fabricada se detectaron
cortocircuitos en varios componentes de montaje superficial (SMD). Ante esta situación, se realizaron trabajos
con el cautín con el fin de corregir las uniones de soldadura defectuosas.
Sin embargo, el tamaño reducido de los encapsulados involucrados 
hizo que esto resultara técnicamente exigente. En algunos casos,
el proceso derivó en el deterioro o remoción física de los componentes afectados, con el
propósito de evitar daños adicionales sobre las pistas y el substrato de la tarjeta.\\

De manera específica, los \textit{level shifters} LS\_2, LS\_3 y LS\_4, y el \textit{buffer} GB1 fueron removidos
como consecuencia de cortocircuitos detectados durante el ensamblaje o durante el proceso
de retrabajo. Adicionalmente, se constató que el regulador de 1.8\,V no quedó correctamente
fijado a la tarjeta tras el proceso de soldadura, constituyendo una deficiencia de ensamblaje adicional.

\begin{figure}[H]
    \centering
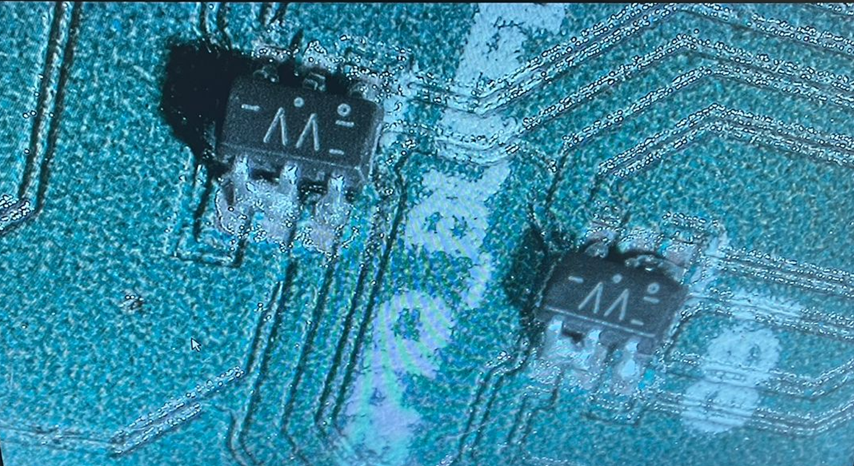
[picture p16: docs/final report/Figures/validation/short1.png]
    
    \caption{Cortocircuitos detectados en componentes SMD tras el ensamblaje de la tarjeta.}
\end{figure}

\begin{figure}[H]
    \centering
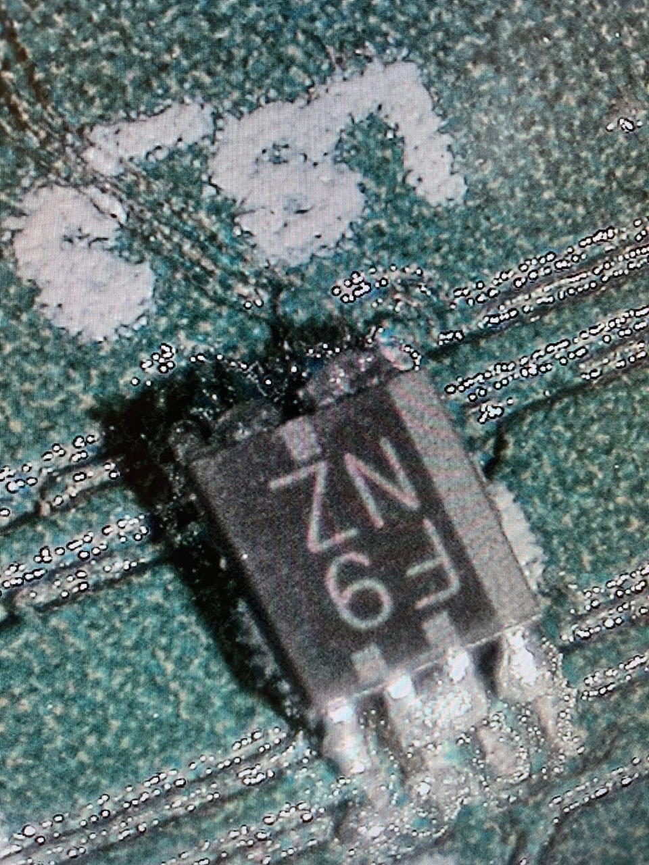
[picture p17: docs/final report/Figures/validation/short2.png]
    
    \caption{Cortocircuito detectado en componente SMD tras el ensamblaje de la tarjeta.}
\end{figure}

\begin{figure}[H]
    \centering
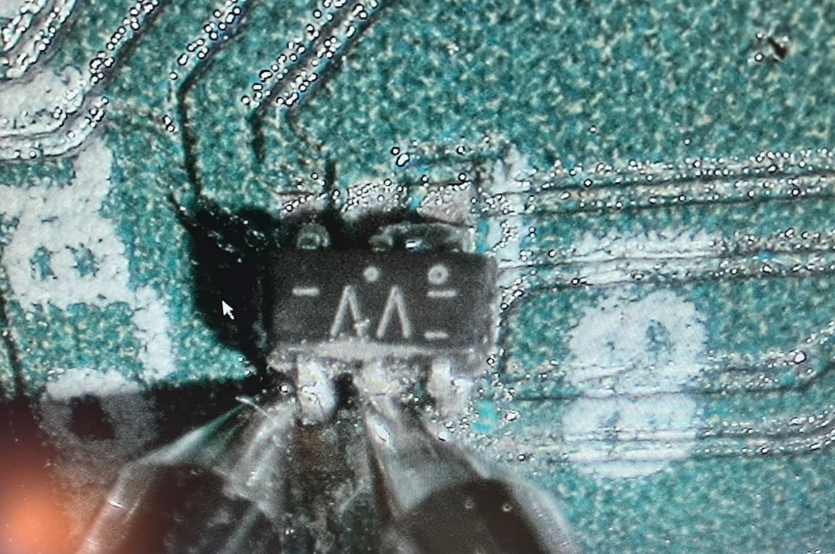
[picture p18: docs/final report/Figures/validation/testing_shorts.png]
    
    \caption{Verificación de continuidad con el multímetro para comprobar cortocircuitos.}
\end{figure}

\begin{figure}[H]
    \centering
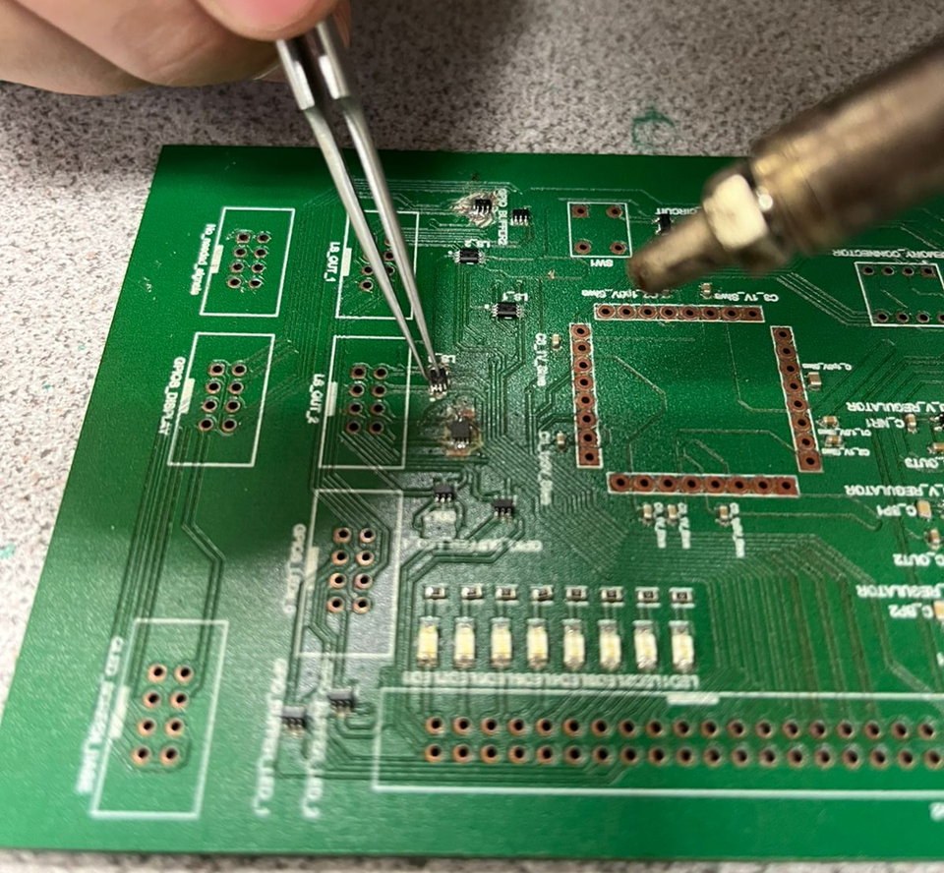
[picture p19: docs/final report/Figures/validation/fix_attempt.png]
    
    \caption{Intento de reparación de los cortocircuitos.}
\end{figure}

\begin{figure}[H]
    \centering
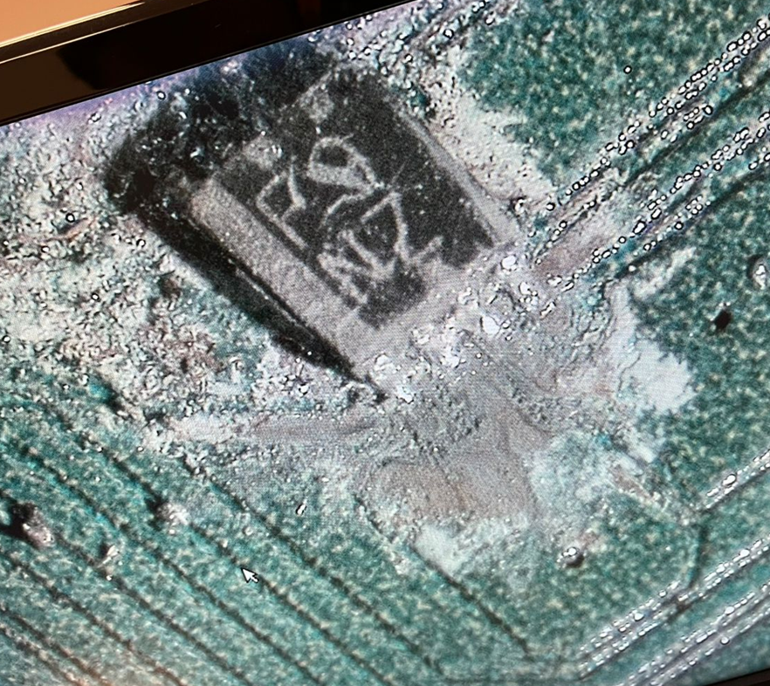
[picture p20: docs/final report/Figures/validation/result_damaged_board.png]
    
    \caption{Deterioro y remoción de componentes SMD durante el proceso de retrabajo,
             incluyendo \textit{level shifters} y \textit{buffer} afectados por cortocircuito.}
\end{figure}

%---------------------------------------------------------
\subsection{Prueba de continuidad}
%---------------------------------------------------------

Con el propósito de conocer el estado eléctrico de la tarjeta de manera sistemática,
se realizaron pruebas de continuidad utilizando un multímetro. El procedimiento consistió en comparar
la conectividad eléctrica medida sobre la PCB fabricada contra la topología de conexiones
definida en el diseño original realizado en \textit{Altium Designer}, empleando el esquemático y
el \textit{layout} como referencia. Se verificaron los siguientes bloques y elementos: 

\begin{itemize}
    \item Conector de alimentación (\textit{Power\_header} 4$\times$2)
    \item Conector de interfaz \textit{HEADER\_20x2} de 40 pines
    \item Reguladores de voltaje (MAX8510EXK30+T para 3\,V, MAX8510EXK18+T para 1.8\,V y TPS71710DCKT para 1\,V)
    \item Oscilador ASE3-20.000MHZ-KT y su \textit{buffer} de reloj
    \item Conector de memoria (\textit{MEMORY\_CONNECTOR})
    \item Conectores de Siwa (\textit{Siwa\_receiver\_1} a \textit{Siwa\_receiver\_4}), 
    \item \textit{Level shifters} TCA9406DCUR, 
    \item \textit{Buffers} para GPIOs (74LVC2G17GW)
    \item Base para la pantalla OLED (\textit{OLED\_SCREEN\_BASE})
    \item LEDs con sus resistencias limitadoras de corriente
    \item Conectores de señales auxiliares (\textit{GPIOs\_LEDs}, \textit{GPIOs\_Display}, \textit{No\_needed\_signals})
\end{itemize}

Los resultados muestran bastantes discontinuidades eléctricas. 
Las conexiones establecidas completamente dentro de una misma capa
de cobre mostraron, en términos generales, continuidad eléctrica adecuada. En contraste,
la gran mayoría de las conexiones que requieren transición entre capas a través de vías
o elementos \textit{through-hole} presentaron discontinuidad eléctrica.\\

Las tensiones de
salida de los tres reguladores no se distribuyen hacia los bloques que las requieren, dado
que las rutas de distribución implican transiciones entre capas mediante vías; los pines de
alimentación (1\,V, 1.8\,V y 3\,V) y de GND que dependen de
vías no presentan continuidad hacia los nodos destino; las señales SPI asociadas a la
memoria externa muestran ausencia de continuidad desde los pines correspondientes del
microcontrolador; las señales GPIO hacia la pantalla OLED y sus \textit{buffers} aparecen
interrumpidas; y múltiples pines de los \textit{level shifters} y \textit{buffers} de GPIOs tienen
desconexión eléctrica respecto a sus fuentes o destinos de señal.\\

El conector \textit{No\_needed\_signals} mostró continuidad correcta en todas sus señales hacia el microcontrolador. 
El nodo de GND resultó alcanzable en los headers de interfaz con Siwa. Durante las pruebas del \textit{switch} de 
reinicio se detectó que el pin 4 del componente, que según el diseño debe conectarse a GND, 
aparecía eléctricamente desconectado, lo cual se analiza en detalle en la sección siguiente.

\begin{figure}[H]
    \centering
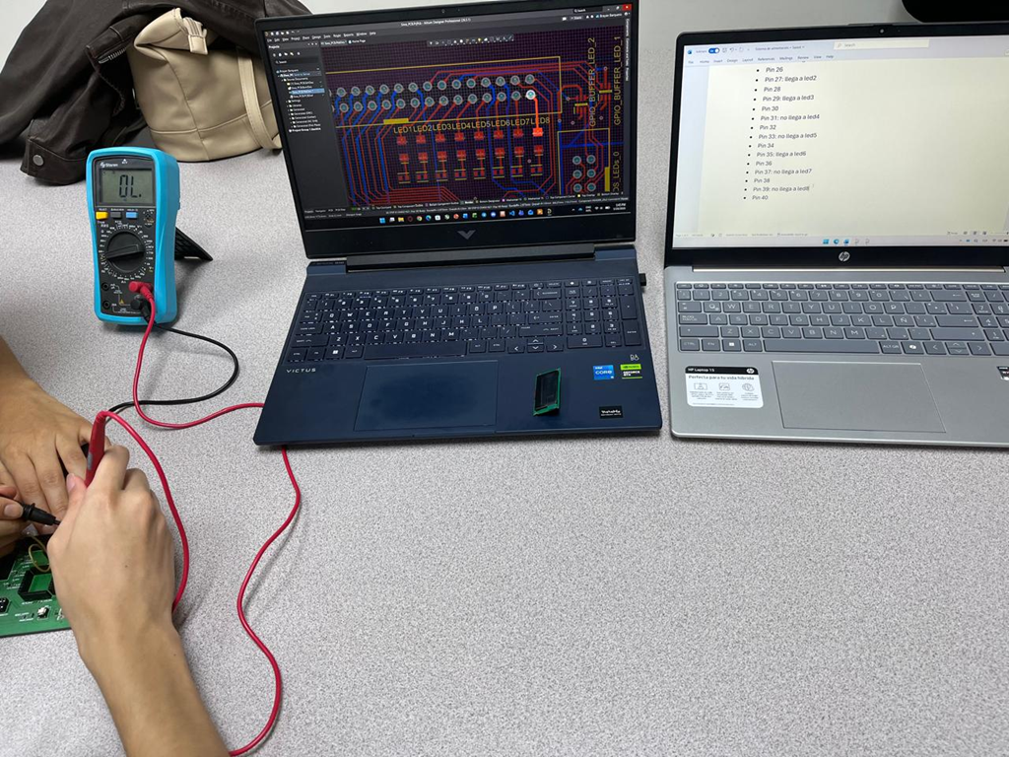
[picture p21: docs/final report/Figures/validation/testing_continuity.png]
    
    \caption{Verificación de continuidad entre bloques de la PCB.}
\end{figure}

%---------------------------------------------------------
\subsection{Validación del sistema de alimentación}
%---------------------------------------------------------

Utilizando una fuente de tensión DC se inyectó controladamente 5\,V a la entrada de alimentación los reguladores de voltaje, 
sin embargo, al medir las tensiones de salida habían discrepancias con lo esperado, debido a esto, 
se verificaron las conexiones de GND asociadas a los reguladores de voltaje, estas conexiones
son a través de vías, de forma que la falta de continuidad en dichas vías priva
a los reguladores del GND necesario para su correcto funcionamiento.
Esta condición explica por qué, a pesar de que la tensión de entrada a los reguladores
se encuentra disponible, los dispositivos no pueden establecer las tensiones de salida esperadas. 
Adicionalmente, el regulador de 1.8\,V presentó la dificultad adicional de no haber quedado correctamente soldado al
substrato durante el ensamblaje, lo que agravó la situación de ese nodo en particular.

%---------------------------------------------------------
\subsection{Verificación del oscilador}
%---------------------------------------------------------

Debido al sistema de alimentación defectuoso de la tarjeta, se procedió a alimentar externamente el oscilador
ASE3-20.000MHZ-KT mediante la fuente de alimentación DC, suministrando directamente la
tensión nominal de operación de 1.8\,V a sus pines correspondientes, sin depender de las
rutas de distribución de potencia de la PCB.\\

Con el oscilador así alimentado, se conectó un osciloscopio al pin de salida del componente
para verificar la señal generada. La medición reveló la presencia de una oscilación
periódica estable con una frecuencia de 20\,MHz, valor que coincide con la frecuencia
nominal especificada por el fabricante.\\

El oscilador opera correctamente cuando recibe alimentación adecuada, lo que indica que
el componente no presenta defectos intrínsecos ni daños atribuibles al proceso de
ensamblaje. La cadena de señal de reloj interna de la tarjeta
(oscilador $\rightarrow$ \textit{CLK\_buffer}) resultó completamente
continua según las pruebas con el osciloscopio. Su limitación operativa se
debe exclusivamente a la imposibilidad de recibir alimentación a través del sistema de
distribución de potencia de la tarjeta.

\begin{figure}[H]
    \centering
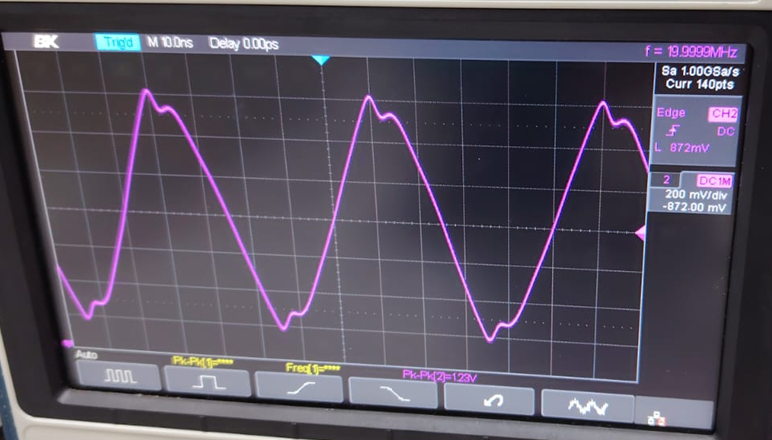
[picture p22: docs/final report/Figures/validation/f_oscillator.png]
    
    \caption{Medición de la señal de salida del oscilador ASE3-20.000MHZ-KT mediante
             osciloscopio con alimentación externa directa.}
\end{figure}

%---------------------------------------------------------
\subsection{Verificación funcional de LEDs}
%---------------------------------------------------------

Se realizó una prueba sobre el LED\,2, correspondiente a uno de los ocho LEDs azules 
presentes en la tarjeta. El objetivo fue determinar si el bloque compuesto
por el LED y su resistencia limitadora de corriente en serie es funcional en condiciones
de alimentación directa, con independencia de las interrupciones presentes en el sistema
de distribución de señales de la PCB.\\

Para realizar la prueba, se inyectaron 3\,V directamente sobre el pin del conector
\textit{HEADER\_20x2} que se encuentra conectado al ánodo del LED\,2, correspondiente
al pin\,27 del mencionado conector según la topología de conexiones del diseño. Dado que
la conexión de GND desde la resistencia limitadora en serie se encontraba
interrumpida por la misma condición de discontinuidad observada en el resto de la tarjeta,
dicha conexión fue puenteada externamente durante la prueba. Las mediciones obtenidas con el multímetro fueron las siguientes:

\begin{itemize}
    \item Caída de tensión sobre el LED: $V_\text{LED} = 2.59\,\text{V}$
    \item Caída de tensión sobre la resistencia en serie: $V_R = 0.464\,\text{V}$
    \item Resistencia en serie: $R = 300\,\Omega$\\
\end{itemize}

A partir de estas mediciones, la corriente de operación del LED se calcula aplicando la
Ley de Ohm a la resistencia limitadora de corriente:

\[
I = \frac{V_R}{R}
\]

\[
I = \frac{0.464}{300}
\]

\[
I \approx 1.55\,\text{mA}
\]

La suma de las caídas de tensión medidas ($2.59\,\text{V} + 0.464\,\text{V} = 3.054\,\text{V}$)
es consistente con la tensión de alimentación aplicada de 3\,V, dentro de las tolerancias
propias del instrumento de medición. La corriente de operación obtenida (1.55\,mA) y la caída de 
tensión medida (2.59\,V) es correcta según la hoja de datos del LED utilizado.\\

Esta prueba demuestra que el bloque LED\,2 y su resistencia asociada funcionan
correctamente, y que la ruta de señal entre el pin 27 del \textit{HEADER\_20x2} y el ánodo
del LED presenta continuidad eléctrica.

\begin{figure}[H]
    \centering
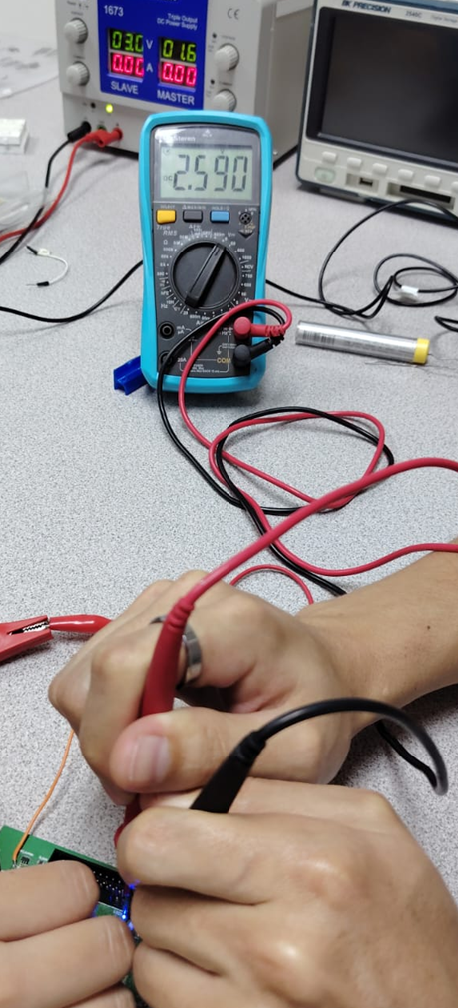
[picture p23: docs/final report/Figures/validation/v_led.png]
    
    \caption{Prueba del LED\,2 con alimentación directa puenteada desde el
             \textit{HEADER\_20x2}. Se indica la medición de caída de tensión en el
             LED ($2.59\,\text{V}$).}
\end{figure}

\begin{figure}[H]
    \centering
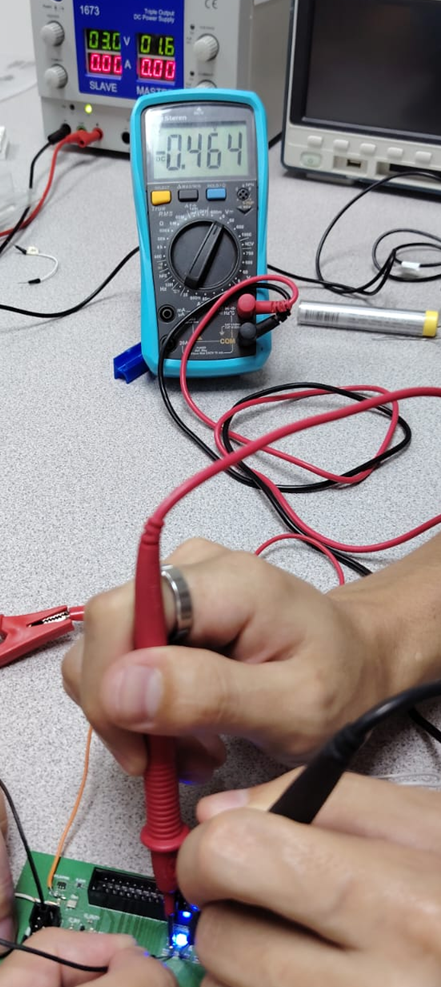
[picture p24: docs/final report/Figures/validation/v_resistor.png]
    
    \caption{Prueba del LED\,2 con alimentación directa puenteada desde el
             \textit{HEADER\_20x2}. Se indica la medición de caída de tensión 
             en la resistencia en serie ($0.464\,\text{V}$).}
\end{figure}

%---------------------------------------------------------
\subsection{Caracterización de resistencia e integridad de señal en pistas}
%---------------------------------------------------------

Con el objetivo de conocer el comportamiento eléctrico de
las pistas de la tarjeta y observar el efecto de las transiciones entre capas sobre
la integridad de señal, se realizó una serie de mediciones utilizando un generador de
funciones y un osciloscopio. Se seleccionaron tres pistas de la tarjeta
y en cada una se inyectó una señal cuadrada de amplitud 1\,V 
a cuatro frecuencias: 20\,kHz, 50\,kHz, 100\,kHz y 1\,MHz. El límite superior de
1\,MHz se estableció debido a que a partir de esa frecuencia el generador de funciones
comenzaba a deformar la señal cuadrada. Adicionalmente, se midió la resistencia de cada pista
con el multímetro.\\

Previo a las mediciones, los cables de prueba del multímetro fueron medidos de forma
independiente, obteniéndose una resistencia de 10.3\,$\Omega$, valor que representa
un desplazamiento en todas las lecturas de resistencia de pistas.

\begin{figure}[H]
    \centering
    
    \caption{Resistencia de los cables de medida: 10.3\,$\Omega$.}
\end{figure}

Los valores de resistencia medidos en las tres pistas, junto con los valores netos
descontando la contribución de los cables, se resumen en la
Tabla~\ref{tab:pistas_resistencia}.

\begin{table}[H]
\centering
\caption{Resistencia medida en las tres pistas analizadas.}
\label{tab:pistas_resistencia}
\begin{tabular}{clcc}
\hline
\textbf{Pista} & \textbf{Descripción} &
$\boldsymbol{R_\text{medida}}$ (\si{\ohm}) &
$\boldsymbol{R_\text{neta}}$ (\si{\ohm}) \\
\hline
1 & GND: \textit{Power\_header} $\rightarrow$ Siwa          &  79.1 &  68.8 \\
2 & GPIO de Siwa $\rightarrow$ \textit{HEADER\_20x2}        & 320.0 & 309.7 \\
3 & \textit{Buffer} GPIO $\rightarrow$ \textit{HEADER\_20x2} & 404.5 & 394.2 \\
\hline
\end{tabular}
\end{table}

%--- Pista 1 ---
\subsubsection{Pista 1: GND del \textit{Power\_header} al GND de Siwa}

La primera pista analizada corresponde a la ruta de GND que conecta el
\textit{Power\_header} con el nodo de tierra del microcontrolador Siwa. Esta pista se
ubica completamente dentro de la capa inferior de la PCB, sin requerir transición entre
capas mediante vías o \textit{through-holes}.

\begin{figure}[H]
    \centering
    
    \caption{Ubicación de la Pista~1 en el \textit{layout}: ruta de GND del
             \textit{Power\_header} al GND de Siwa.}
\end{figure}

\begin{figure}[H]
    \centering
    
    \caption{Medición de resistencia de la Pista~1: 79.1\,$\Omega$.}
\end{figure}

La propagación de la señal cuadrada fue adecuada a 20\,kHz, 50\,kHz y 100\,kHz, con
formas de onda bien definidas en ambos extremos de la pista. A 1\,MHz se observa
una deformación de la señal, pero esto se debe en gran parte a que la señal
de entrada viene deformada desde el generador de funciones.

\begin{figure}[H]
    \centering
    \begin{minipage}[b]{0.48\linewidth}
        \centering
        
    \end{minipage}
    \hfill
    \begin{minipage}[b]{0.48\linewidth}
        \centering
        
    \end{minipage}
    \caption{Pista~1: señal cuadrada a 20\,kHz (izquierda) y 50\,kHz (derecha).
             Canal~1 (amarillo): señal inyectada. Canal~2 (magenta): señal de salida.}
\end{figure}

\begin{figure}[H]
    \centering
    \begin{minipage}[b]{0.48\linewidth}
        \centering
        
    \end{minipage}
    \hfill
    \begin{minipage}[b]{0.48\linewidth}
        \centering
        
    \end{minipage}
    \caption{Pista~1: señal cuadrada a 100\,kHz (izquierda) y 1\,MHz (derecha).}
\end{figure}

\subsubsection{Pista 2: Salida de GPIO de Siwa al \textit{HEADER\_20x2}}

La segunda pista corresponde a la ruta de señal entre la salida de un GPIO del
microcontrolador Siwa y el conector \textit{HEADER\_20x2}. Al igual que la Pista~1,
esta conexión se establece dentro de la capa inferior de la PCB.

\begin{figure}[H]
    \centering
    
    \caption{Ubicación de la Pista~2 en el \textit{layout}: señal GPIO de Siwa al
             \textit{HEADER\_20x2}.}
\end{figure}

\begin{figure}[H]
    \centering
    
    \caption{Medición de resistencia de la Pista~2: 320.0\,$\Omega$.}
\end{figure}

La resistencia de 320.0\,$\Omega$ es notablemente superior a la de la Pista~1, lo cual
es consistente con una mayor longitud o menor sección transversal de la pista, en este caso
mayoritariamente la segunda, debido a que la Pista~1 tiene un plano completo en la capa inferior. A pesar de
este valor, la señal se propaga correctamente,
produciendo una deformación más pronunciada a 1\,MHz debido a la entrada deformada desde el generador de funciones.

\begin{figure}[H]
    \centering
    \begin{minipage}[b]{0.48\linewidth}
        \centering
        
    \end{minipage}
    \hfill
    \begin{minipage}[b]{0.48\linewidth}
        \centering
        
    \end{minipage}
    \caption{Pista~2: señal cuadrada a 20\,kHz (izquierda) y 50\,kHz (derecha).}
\end{figure}

\begin{figure}[H]
    \centering
    \begin{minipage}[b]{0.48\linewidth}
        \centering
        
    \end{minipage}
    \hfill
    \begin{minipage}[b]{0.48\linewidth}
        \centering
        
    \end{minipage}
    \caption{Pista~2: señal cuadrada a 100\,kHz (izquierda) y 1\,MHz (derecha).}
\end{figure}

\subsubsection{Pista 3: Del \textit{buffer} de GPIO al \textit{HEADER\_20x2}}

La tercera pista presenta una característica diferencial respecto a las anteriores:
aunque la traza de cobre se ubica completamente en el plano superior del sustrato, la
medición se realizó en los pines del conector \textit{HEADER\_20x2}, cuyos terminales
están soldados al plano inferior. Para que la señal alcance el punto de medición debe,
por lo tanto, transitar por la metalización del \textit{through-hole} del
conector.

\begin{figure}[H]
    \centering
    
    \caption{Ubicación de la Pista~3 en el \textit{layout}: ruta del \textit{buffer} de
             GPIO al \textit{HEADER\_20x2}.}
\end{figure}

\begin{figure}[H]
    \centering
    
    \caption{Medición de resistencia de la Pista~3: 404.5\,$\Omega$.}
\end{figure}

La resistencia medida de 404.5\,$\Omega$ es la más alta de las tres pistas analizadas.
Este resultado es significativo porque la traza de cobre en sí misma está contenida en
una sola capa; su resistencia intrínseca no debería ser sustancialmente mayor a la de las
pistas anteriores para una longitud comparable. La resistencia adicional observada apunta
a una contribución importante de la interfaz \textit{through-hole}, lo que es consistente
con una metalización parcial o degradada en el barril del conector.\\

El comportamiento en el dominio de la frecuencia refuerza esta interpretación. A 20\,kHz
y 50\,kHz la señal se propaga, pero con una degradación ligera en la señal. A 100\,kHz la degradación
de la forma de onda es notoria, y a 1\,MHz la señal pierde completamente la forma
cuadrada. Este comportamiento es una consecuencia de la resistencia adicional introducida por
el \textit{through-hole}. Los hallazgos son consistentes con una metalización existente
pero defectuosa en la interfaz entre capas, condición que introduce una resistencia
parásita elevada sin producir una interrupción eléctrica completa.

\begin{figure}[H]
    \centering
    \begin{minipage}[b]{0.48\linewidth}
        \centering
        
    \end{minipage}
    \hfill
    \begin{minipage}[b]{0.48\linewidth}
        \centering
        
    \end{minipage}
    \caption{Pista~3: señal cuadrada a 20\,kHz (izquierda) y 50\,kHz (derecha).}
\end{figure}

\begin{figure}[H]
    \centering
    \begin{minipage}[b]{0.48\linewidth}
        \centering
        
    \end{minipage}
    \hfill
    \begin{minipage}[b]{0.48\linewidth}
        \centering
        
    \end{minipage}
    \caption{Pista~3: señal cuadrada a 100\,kHz (izquierda) y 1\,MHz (derecha).}
\end{figure}

Los resultados de esta subsección aportan evidencia que complementa el
diagnóstico basado en pruebas de continuidad. La comparación entre las tres pistas
establece que: las rutas contenidas completamente en un único plano
conductor presentan propagación de señal adecuada y resistencia en el rango esperado,
mientras que la ruta que involucra una transición por \textit{through-hole} exhibe
resistencia elevada y degradación de señal acelerada con la frecuencia.
Estos hallazgos son consistentes con la presencia de una metalización defectuosa en la
interfaz entre capas, y refuerzan la hipótesis de que el mecanismo de fallo predominante
en la tarjeta está asociado a las interconexiones \textit{through-hole} y de vías.

\subsection{Clasificación del estado funcional por bloques}

Los resultados de las pruebas permiten clasificar los bloques de la tarjeta según su
estado funcional observado. El oscilador tiene un correcto funcionamiento
con alimentación externa (20\,MHz verificados mediante osciloscopio), y la cadena interna
de reloj presenta continuidad eléctrica correcta. El LED\,2 opera adecuadamente cuando
se le proporciona alimentación de manera directa, con valores de
corriente y tensión son consistentes con las características del componente. El
conector \textit{No\_needed\_signals} mostró continuidad correcta en todas sus señales
hacia el microcontrolador.\\

Los bloques que no pudieron operar bajo las condiciones de la tarjeta
fabricada incluyen: la distribución de las tensiones de alimentación de 3\,V, 1.8\,V y
1\,V hacia los bloques consumidores; el sistema de interfaz SPI hacia la memoria externa
SST25WF080B, sin continuidad eléctrica entre los pines de Siwa y los pines del conector
de memoria; los cuatro \textit{level shifters} TCA9406DCUR (tres de los cuales fueron
además removidos físicamente de la tarjeta); los \textit{buffers} GPIO 74LVC2G17GW asociados tanto
a los LEDs como a la pantalla OLED; la pantalla OLED, sin señales de control ni
alimentación adecuadas; y la mayoría de las señales del conector \textit{HEADER\_20x2}
que requieren transiciones entre capas para su correcto funcionamiento.

\subsection{Patrón de fallos y diferenciación entre error de diseño y error de
fabricación}

El patrón de fallos no es aleatorio ni atribuible a un único bloque funcional, sino que es sistemático y afecta a la
totalidad de la tarjeta. Cada fallo observado corresponde a una conexión que, según el
\textit{layout} diseñado en \textit{Altium Designer}, requiere la transición entre capas de cobre
a través de una vía o un elemento \textit{through-hole}. En contraste, las conexiones
establecidas completamente dentro de una misma capa de cobre demostraron continuidad
eléctrica correcta en todos los casos verificados.\\

Si el origen de los fallos
fuera un error de diseño en el esquemático o en el \textit{layout}, cabría esperar fallos
específicos y localizados en bloques concretos, vinculados a errores de conexión puntuales
y sin un mecanismo de fallo común. Sin embargo, el hecho de que múltiples bloques
funcionales independientes entre sí (el sistema de alimentación, la interfaz de memoria,
el control de la pantalla OLED, los \textit{buffer} de LEDs y los \textit{level shifters}) presenten
fallos de manera simultánea bajo el mismo mecanismo hace que resulte inconsistente
atribuir la causa a errores de diseño particulares. Los fallos son hallazgos consistentes
con un problema estructural de la tarjeta.\\

No obstante, el proceso de diagnóstico permitió identificar una segunda categoría
de fallo, de naturaleza distinta y atribuible al diseño. Durante las pruebas sobre el
\textit{switch} de reinicio SW1 (B3F-1000s) se verificó que el pin 4 del componente,
correspondiente al nodo de GND, no presentaba continuidad con el plano de tierra de la
tarjeta. El análisis del \textit{footprint} utilizado reveló que los pines 1 y 4 están
intercambiados respecto al componente real: el esquemático es correcto y sus conexiones
coinciden con la hoja de datos del fabricante, pero el \textit{footprint} obtenido de
una biblioteca de terceros no representa fielmente la disposición física de las patillas
del componente. Como consecuencia, la red de GND queda físicamente soldada a la
ubicación de la patilla que el componente real asigna al terminal opuesto, produciendo
una conexión permanente de GND sobre la línea de reinicio del sistema. Dado que la
señal de \textit{reset} opera activa en bajo, esta condición mantiene al microcontrolador
en estado de reinicio de forma permanente, sin posibilidad de corrección por retrabajo.
Este hallazgo constituye un error de diseño verificable e independiente del problema de
metalización.

\subsection{Hipótesis sobre la causa del fallo}

A partir de la evidencia acumulada, los resultados sugieren que los fallos observados son
atribuibles a deficiencias en la metalización de las vías y conexiones
\textit{through-hole} de la tarjeta fabricada. En una tarjeta de circuito impreso
multicapa, la metalización de las vías constituye el mecanismo físico que garantiza el
paso de corriente eléctrica entre capas de cobre. Si dicha metalización es deficiente o
inexistente, cualquier conexión que requiera transitar por esa vía queda eléctricamente
abierta, independientemente de si las pistas en las capas adyacentes están correctamente
diseñadas y fabricadas.\\

Esta condición explicaría de manera
unificada la totalidad de los fenómenos observados: la imposibilidad de distribución de las
tensiones de alimentación, la ausencia de retorno de GND funcional en los reguladores de
voltaje, la interrupción de las señales SPI hacia la memoria, la desconexión de las señales
GPIO hacia la pantalla OLED y sus \textit{buffers}, y la falta de continuidad en los
\textit{level shifters} y \textit{buffers} de señal.\\

La diferencia entre los bloques funcionales y los no funcionales es coherente con esta
interpretación. Los elementos que operaron correctamente (la cadena de reloj, las
señales \textit{No\_needed\_signals}, el GND en ciertos nodos y los LEDs con alimentación
puenteada) comparten la característica de estar interconectados predominantemente en la
misma capa de cobre, sin requerir transiciones entre capas para establecer su
conectividad. Los elementos que no funcionaron dependen, sin excepción, de vías para
establecer sus interconexiones funcionales, ya sea para las señales de control, para la
alimentación o para GND.\\

En cuanto a los cortocircuitos detectados durante el ensamblaje y el retrabajo
subsiguiente que resultó en la remoción de algunos \textit{level shifters}, esto se debe 
a la poca experiencia y a la complejidad del proceso de
ensamblaje, relacionado con dificultades inherentes a los encapsulados de
dimensiones reducidas. No obstante, incluso en ausencia de dichos cortocircuitos, la
falta de continuidad en las vías habría impedido igualmente la operación de los bloques
afectados, ya que la ruta eléctrica entre el microcontrolador y cada uno de esos
componentes transita obligatoriamente por vías.

%---------------------------------------------------------
\subsection{Conclusiones del proceso de validación}
%---------------------------------------------------------

El proceso de validación de la tarjeta de pruebas del microcontrolador Siwa se realizó
siguiendo un procedimiento sistemático de diagnóstico, estructurado en etapas progresivas
que permitieron acumular evidencia experimental de manera ordenada.\\

La metodología aplicada permitió distinguir con claridad entre errores de diseño y errores
de fabricación. La evidencia experimental acumulada indica que el esquemático y el
\textit{layout} del sistema son funcionalmente correctos: el oscilador opera a 20\,MHz con
alimentación directa, el LED\,2 funciona con los valores de corriente y tensión esperados
($I \approx 1.55\,\text{mA}$, $V_\text{LED} = 2.59\,\text{V}$), y las rutas de señal en
capa única presentan continuidad eléctrica adecuada. Estos resultados descartan errores en el 
esquemático eléctrico como causa raíz de los fallos generalizados observados. Sin embargo, 
el proceso de diagnóstico identificó un error de diseño puntual en el \textit{footprint} 
del \textit{switch} SW1, cuyos pines 1 y 4 están intercambiados respecto al componente real, 
provocando una condición de reinicio permanente del microcontrolador.\\

En contraste, todas las conexiones que implican transiciones entre capas mediante vías o
elementos \textit{through-hole} presentaron discontinuidad eléctrica. Los resultados sugieren que la principal causa de fallo corresponde a
problemas de metalización en vías y conexiones \textit{through-hole}, afectando la
continuidad eléctrica entre capas. Esta condición es consistente con la totalidad de los
síntomas observados: la imposibilidad de distribución de potencia, la interrupción de
señales de control en bloques independientes, y la inoperatividad generalizada de la
tarjeta bajo condiciones de alimentación estándar. La evidencia obtenida apunta a un
defecto de fabricación que afecta específicamente la interconexión entre capas, y no a
errores conceptuales en el diseño eléctrico del sistema.

%\\\\\\\\\\\\\\\\\\\\\\\\\\\\\\\\\\\\\\\\\\\\\\
%Proceso operativo
%\\\\\\\\\\\\\\\\\\\\\\\\\\\\\\\\\\\\\\\\\\\\\\

\section{Proceso operativo}
%¿Cómo fue organizado el trabajo y la asignación de tareas y responsabilidades entre los miembros del grupo?

%B: Project Manager | Yo: Scrum Master | P: Miembro | F: Miembro
%Metodología Ágil Scrum
%Eventos puntuados
%Issues
%Sprint backlog

\subsection{Planificación general del proyecto}
El desarrollo del proyecto se organizó mediante una metodología ágil basada en Scrum. Para la planificación general se elaboró un diagrama de Gantt, mostrado en la Figura~\ref{fig:gantt}, en el cual se distribuyeron las principales etapas del proyecto a lo largo del semestre. Este cronograma incluyó las actividades iniciales de aprendizaje de Scrum, Altium Designer y GitHub, seguidas por la revisión de componentes, la elaboración del esquemático, el diseño del PCB, la revisión de la propuesta, la fabricación, el ensamblaje, la validación, la documentación y la presentación final. El diagrama permitió establecer una secuencia general de trabajo y visualizar los principales hitos y periodos asignados a cada etapa.

\subsection{Seguimiento y coordinación del trabajo}
El seguimiento detallado de las actividades se realizó mediante un tablero de GitHub. Las tareas se incorporaron inicialmente al \textit{Product Backlog} y, al comienzo de cada ciclo de trabajo, se seleccionaron aquellas que formarían parte del \textit{Sprint Backlog}. Cada tarea incluía una descripción, un responsable y un estado dentro del flujo de trabajo. Conforme avanzaba su ejecución, las tareas se desplazaban por los estados \textit{In Progress}, \textit{Review/Testing} y \textit{Done}. Además, los integrantes trabajaron en ramas independientes y utilizaron \textit{Pull Requests} para revisar e integrar los cambios al repositorio principal. En la figura~\ref{fig:backlog} se muestra el tablero de Github.\\

Para complementar el seguimiento del tablero se realizaron reuniones \textit{Daily Stand-Up} (DSU). Durante las primeras etapas del proyecto se efectuaron tres reuniones por semana; sin embargo, en las etapas finales la frecuencia se redujo a una reunión semanal, de acuerdo con las necesidades y el estado del proyecto. En cada reunión, los integrantes respondían tres preguntas principales: qué habían completado desde la reunión anterior, en qué trabajarían hasta la siguiente reunión y si existía algún bloqueo que afectara el avance de sus tareas. También se registraban observaciones, decisiones y notas adicionales relacionadas con el proyecto.\\

La información correspondiente a cada reunión se documentó en un libro de Excel. Este registro permitió conservar evidencia del progreso de los integrantes, de las actividades planificadas para el siguiente periodo y de los obstáculos identificados durante el desarrollo. En la Figura~\ref{fig:dsu} se muestra un ejemplo del formato utilizado para documentar una de estas reuniones.

\begin{figure}[h]
\centering

\caption{Registro de una reunión \textit{Daily Stand-Up} para el seguimiento de las tareas del proyecto.}
\label{fig:dsu}
\end{figure}

\subsection{Asignación de roles y responsabilidades}
La asignación de responsabilidades se realizó de acuerdo con los roles definidos para el equipo. Brayan desempeñó el rol de \textit{Product Owner}. Entre sus responsabilidades se encontraron definir y priorizar las tareas del \textit{Product Backlog}, verificar que el tablero se mantuviera actualizado, revisar los \textit{Pull Requests} y aprobar los cambios o solicitar correcciones. También comprobó que los entregables cumplieran los criterios de aceptación antes de trasladarlos al estado \textit{Done}. Además de estas funciones de coordinación y revisión, tomó tareas del \textit{Sprint Backlog} y contribuyó técnicamente al proyecto mediante el trabajo en ramas dedicadas.\\

Jeffrey desempeñó el rol de \textit{Scrum Master}. Se encargó de determinar, en conjunto con el equipo, cuáles tareas ingresarían en cada \textit{sprint} y de dirigir las reuniones de seguimiento. También identificó los bloqueos comunicados por los integrantes y colaboró en la búsqueda de soluciones. Asimismo, verificó que cada tarea tuviera una descripción clara y un responsable asignado. Como parte de su contribución técnica, trabajó en tareas del \textit{Sprint Backlog}, utilizó ramas independientes y creó \textit{Pull Requests} al completar sus actividades.\\

Priscilla y Fiorela participaron como integrantes del equipo de desarrollo. Sus responsabilidades consistieron en seleccionar las tareas asignadas del \textit{Sprint Backlog}, trasladarlas al estado \textit{In Progress} y desarrollar el trabajo correspondiente en ramas dedicadas. Los cambios realizados se registraban mediante \textit{commits} descriptivos y, una vez finalizada cada actividad, se creaba un \textit{Pull Request} para su revisión. Posteriormente, las tareas se trasladaban a \textit{Review/Testing} y, después de recibir aprobación, a \textit{Done}. También comunicaban durante las reuniones cualquier bloqueo o dificultad que pudiera afectar el cumplimiento de las actividades.

\subsection{Gestión colaborativa del diseño y control de versiones}
Para el desarrollo específico del esquemático y del PCB se utilizó principalmente un \textit{Workspace} compartido de Altium 365. En este espacio se almacenaron los archivos de diseño y se realizaron las modificaciones correspondientes al esquemático, la distribución de componentes y el ruteo de la tarjeta. Los integrantes podían actualizar el proyecto dentro del \textit{Workspace}, lo que permitió mantener disponible para todo el equipo la versión de trabajo más reciente.\\

Altium 365 mantuvo un historial de versiones en el que se registraron las modificaciones realizadas por los diferentes integrantes. Este historial permitió identificar el autor de cada actualización, revisar la secuencia de cambios y conservar trazabilidad sobre la evolución del diseño. La Figura~\ref{fig:altium_365} muestra una parte del árbol de versiones correspondiente al proyecto almacenado en Altium 365.

\begin{figure}[h]
\centering

\caption{Historial de versiones del diseño del PCB en el \textit{Workspace} compartido de Altium 365.}
\label{fig:altium_365}
\end{figure}

El \textit{Workspace} de Altium 365 y el repositorio de GitHub desempeñaron funciones diferentes y complementarias. Altium 365 se utilizó como el entorno principal para la edición colaborativa y el control de versiones del diseño electrónico. Cada integrante podía realizar y registrar cambios sobre los archivos del esquemático y del PCB dentro de este entorno.\\

Después de completar y revisar un conjunto significativo de modificaciones, se incorporaba al repositorio de GitHub una versión consolidada de los archivos del PCB. Por lo tanto, no se trasladaba a GitHub cada cambio menor realizado durante el diseño, sino aquellas versiones correspondientes a etapas consideradas suficientemente completas. GitHub funcionó como el repositorio general del proyecto, mientras que Altium 365 se empleó como el repositorio de trabajo especializado para el desarrollo continuo del circuito impreso.\\

Esta organización permitió diferenciar la planificación general, el seguimiento cotidiano y el trabajo técnico especializado. El diagrama de Gantt proporcionó una visión global del calendario; el tablero de GitHub permitió administrar las tareas y los entregables; las reuniones facilitaron la comunicación y la identificación de bloqueos; y Altium 365 proporcionó el entorno colaborativo necesario para desarrollar y mantener el diseño del PCB.

%\\\\\\\\\\\\\\\\\\\\\\\\\\\\\\\\\\\\\\\\\\\\\\
%Conclusiones
%\\\\\\\\\\\\\\\\\\\\\\\\\\\\\\\\\\\\\\\\\\\\\\

\section{Conclusiones}

%Al menos 1 por miembro del equipo.

El proceso de diseño evidenció que el desarrollo de una PCB no depende únicamente de completar el esquemático y el ruteo inicial, sino también de responder a cambios de requerimientos dentro de plazos limitados. La modificación de las dimensiones de la tarjeta obligó a reorganizar parte del \textit{layout}, reposicionar componentes y actualizar secciones del ruteo, manteniendo la coherencia eléctrica del diseño. Esta experiencia dio paso a comprender mejor la dinámica de un proyecto de ingeniería orientado a un cliente, donde las decisiones técnicas deben ajustarse a nuevas solicitudes sin perder trazabilidad ni control sobre las reglas de diseño.

El proceso de fabricación de la PCB es propenso a errores debido a la manualidad de los pasos involucrados,
desde la aplicación de la pasta de soldadura con el \textit{stencil} hasta la colocación de los componentes de montaje superficial
con ayuda de la máquina de \textit{pick and place}, donde se debe estimar la posición y orientación de cada componente con precisión.

El proceso de validación de la tarjeta PCB permitió establecer, mediante un procedimiento
sistemático de diagnóstico, que la causa principal de inoperatividad de la tarjeta
corresponde a deficiencias de metalización en vías y elementos \textit{through-hole},
condición atribuible al proceso de fabricación y no al diseño eléctrico del sistema.
Las pruebas de continuidad, la validación del sistema de alimentación y la caracterización
de integridad de señal en pistas aportaron evidencia que sustenta esta
conclusión: las rutas contenidas en una sola capa de cobre operaron correctamente, mientras
que todas las conexiones que dependen de transiciones entre capas presentaron discontinuidad
eléctrica o resistencia parásita elevada.

%\\\\\\\\\\\\\\\\\\\\\\\\\\\\\\\\\\\\\\\\\\\\\\
%Referencias
%\\\\\\\\\\\\\\\\\\\\\\\\\\\\\\\\\\\\\\\\\\\\\\

\begin{thebibliography}{1} 
	\bibitem{ipc7351}
	IPC, \textit{IPC-7351B: Generic Requirements for Surface Mount Design and Land Pattern Standard}. Bannockburn, IL, USA: IPC, 2010.
	
	\bibitem{altium_nets}
	Altium, ``Net labels and connectivity in schematics,'' \textit{Altium Designer Documentation}. [Online]. Available: https://www.altium.com/documentation/altium-designer.
	
	\bibitem{altium_schematic}
	Altium, ``Compiling and validating the design,'' \textit{Altium Designer Documentation}. [Online]. Available: https://www.altium.com/documentation/altium-designer.
	
	\bibitem{altium_pcb}
	Altium, ``Transferring design data from schematic to PCB,'' \textit{Altium Designer Documentation}. [Online]. Available: https://www.altium.com/documentation/altium-designer.
	
	\bibitem{ipc2221}
	IPC, \textit{IPC-2221B: Generic Standard on Printed Board Design}. Bannockburn, IL, USA: IPC, 2012.
	
	\bibitem{johnson2003}
	H. Johnson and M. Graham, \textit{High-Speed Signal Propagation: Advanced Black Magic}. Upper Saddle River, NJ, USA: Prentice Hall, 2003.
	
	\bibitem{bogatin2018}
	E. Bogatin, \textit{Signal and Power Integrity--Simplified}, 3rd ed. Upper Saddle River, NJ, USA: Prentice Hall, 2018.
	
	\bibitem{gerber_altium}
	Altium, ``Generating Gerber and NC Drill files,'' \textit{Altium Designer Documentation}. [Online]. Available: https://www.altium.com/documentation/altium-designer.
	
    \bibitem{Clive} C. Maxfield, The design warrior's guide to FPGAs, 1st ed. Amsterdam: Newnes/Elsevier, 2004.
\end{thebibliography}

\onecolumn

\section{Apéndice}

\begin{figure}[h]
    \centering
    
    \caption{Diagrama de Gantt.}
    \label{fig:gantt}
\end{figure}

\begin{figure}[h]
    \centering
    
    \caption{Tablero de Github (\textit{Backlog}).}
    \label{fig:backlog}
\end{figure}

\end{document}








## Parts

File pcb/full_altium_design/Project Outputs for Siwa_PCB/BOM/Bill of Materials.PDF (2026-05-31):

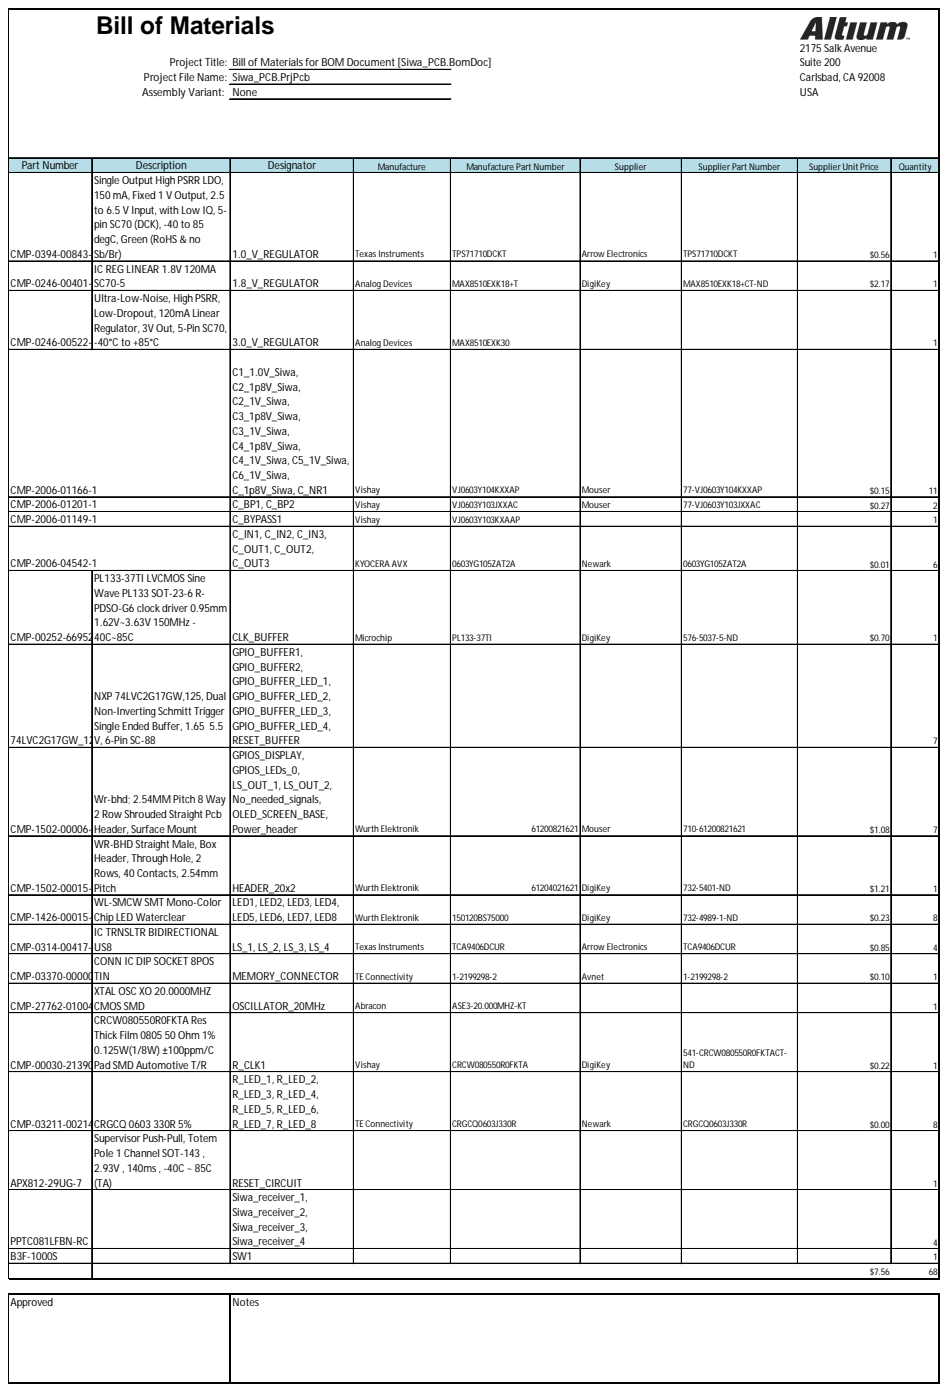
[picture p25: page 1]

Part Number | Description | Designator | Manufacture | Manufacture Part Number | Supplier | Supplier Part Number | Supplier Unit Price | Quantity
CMP-0394-00843-2 | Single Output High PSRR LDO, 150 mA, Fixed 1 V Output, 2.5 to 6.5 V Input, with Low IQ, 5-pin SC70 (DCK), -40 to 85 degC, Green (RoHS & no Sb/Br) | 1.0_V_REGULATOR | Texas Instruments | TPS71710DCKT | Arrow Electronics | TPS71710DCKT | $0.56 | 1

CMP-0246-00401-2 | IC REG LINEAR 1.8V 120MA SC70-5 | 1.8_V_REGULATOR | Analog Devices | MAX8510EXK18+T | DigiKey | MAX8510EXK18+CT-ND | $2.17 | 1

CMP-0246-00522-1 | Ultra-Low-Noise, High PSRR, Low-Dropout, 120mA Linear Regulator, 3V Out, 5-Pin SC70, -40°C to +85°C | 3.0_V_REGULATOR | Analog Devices | MAX8510EXK30 | | | | 1

CMP-2006-01166-1 | | C1_1.0V_Siwa, C2_1p8V_Siwa, C2_1V_Siwa, C3_1p8V_Siwa, C3_1V_Siwa, C4_1p8V_Siwa, C4_1V_Siwa, C5_1V_Siwa, C6_1V_Siwa, C_1p8V_Siwa, C_NR1 | Vishay | VJ0603Y104KXXAP | Mouser | 77-VJ0603Y104KXXAP | $0.15 | 11

CMP-2006-01201-1 | | C_BP1, C_BP2 | Vishay | VJ0603Y103JXXAC | Mouser | 77-VJ0603Y103JXXAC | $0.27 | 2
CMP-2006-01149-1 | | C_BYPASS1 | Vishay | VJ0603Y103KXAAP | | | | 1
CMP-2006-04542-1 | | C_IN1, C_IN2, C_IN3, C_OUT1, C_OUT2, C_OUT3 | KYOCERA AVX | 0603YG105ZAT2A | Newark | 0603YG105ZAT2A | $0.01 | 6

CMP-00252-66952958- | PL133-37TI LVCMOS Sine Wave PL133 SOT-23-6 R-PDSO-G6 clock driver 0.95mm 1.62V~3.63V 150MHz -40C~85C | CLK_BUFFER | Microchip | PL133-37TI | DigiKey | 576-5037-5-ND | $0.70 | 1

74LVC2G17GW_125 | NXP 74LVC2G17GW,125, Dual Non-Inverting Schmitt Trigger Single Ended Buffer, 1.65 5.5 V, 6-Pin SC-88 | GPIO_BUFFER1, GPIO_BUFFER2, GPIO_BUFFER_LED_1, GPIO_BUFFER_LED_2, GPIO_BUFFER_LED_3, GPIO_BUFFER_LED_4, RESET_BUFFER | | | | | | 7

CMP-1502-00006-3 | Wr-bhd; 2.54MM Pitch 8 Way 2 Row Shrouded Straight Pcb Header, Surface Mount | GPIOS_DISPLAY, GPIOS_LEDs_0, LS_OUT_1, LS_OUT_2, No_needed_signals, OLED_SCREEN_BASE, Power_header | Wurth Elektronik | 61200821621 | Mouser | 710-61200821621 | $1.08 | 7

CMP-1502-00015-4 | WR-BHD Straight Male, Box Header, Through Hole, 2 Rows, 40 Contacts, 2.54mm Pitch | HEADER_20x2 | Wurth Elektronik | 61204021621 | DigiKey | 732-5401-ND | $1.21 | 1

CMP-1426-00015-3 | WL-SMCW SMT Mono-Color Chip LED Waterclear | LED1, LED2, LED3, LED4, LED5, LED6, LED7, LED8 | Wurth Elektronik | 150120BS75000 | DigiKey | 732-4989-1-ND | $0.23 | 8

CMP-0314-00417-3 | IC TRNSLTR BIDIRECTIONAL US8 | LS_1, LS_2, LS_3, LS_4 | Texas Instruments | TCA9406DCUR | Arrow Electronics | TCA9406DCUR | $0.85 | 4

CMP-03370-000009- | CONN IC DIP SOCKET 8POS TIN | MEMORY_CONNECTOR | TE Connectivity | 1-2199298-2 | Avnet | 1-2199298-2 | $0.10 | 1

CMP-27762-010045- | XTAL OSC XO 20.0000MHZ CMOS SMD | OSCILLATOR_20MHz | Abracon | ASE3-20.000MHZ-KT | | | | 1

CMP-00030-21390498- | CRCW080550R0FKTA Res Thick Film 0805 50 Ohm 1% 0.125W(1/8W) ±100ppm/C Pad SMD Automotive T/R | R_CLK1 | Vishay | CRCW080550R0FKTA | DigiKey | 541-CRCW080550R0FKTACT-ND | $0.22 | 1

CMP-03211-002147- CRGCQ 0603 330R 5% | | R_LED_1, R_LED_2, R_LED_3, R_LED_4, R_LED_5, R_LED_6, R_LED_7, R_LED_8 | TE Connectivity | CRGCQ0603J330R | Newark | CRGCQ0603J330R | $0.00 | 8

APX812-29UG-7 | Supervisor Push-Pull, Totem Pole 1 Channel SOT-143 , 2.93V , 140ms , -40C ~ 85C (TA) | RESET_CIRCUIT | | | | | | 1

PPTC081LFBN-RC | | Siwa_receiver_1, Siwa_receiver_2, Siwa_receiver_3, Siwa_receiver_4 | | | | | | 4

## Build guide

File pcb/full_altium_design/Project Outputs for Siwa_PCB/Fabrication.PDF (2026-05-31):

### Design Rules Verification Report

Filename : C:\Users\Public\Documents\Altium\Siwa_PCB_1\Siwa_PCB.PcbDoc | Warnings 0

### Rule Violations 0

Warnings
Total | 0
Friday 8 May 2026 11:56:21 PM | Page 1 of 3

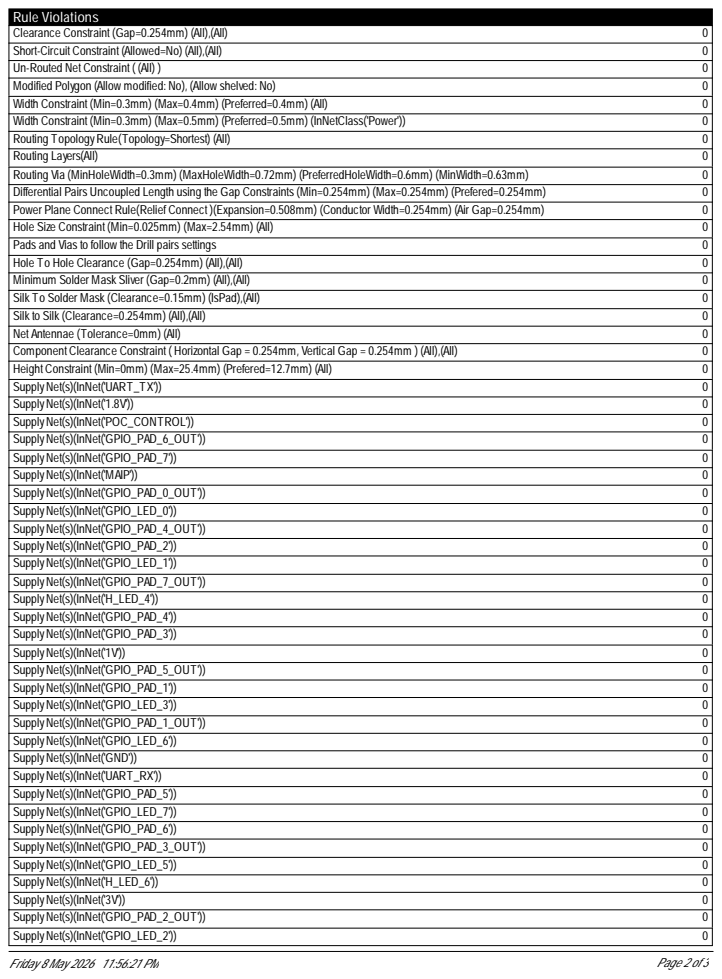
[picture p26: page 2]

Rule Violations
SupplyNet(s)(InNet('GPIO_LED_4')) | 0
SupplyNet(s)(InNet('H_LED_7')) | 0
SupplyNet(s)(InNet('H_LED_5')) | 0
SupplyNet(s)(InNet('GPIO_PAD_0')) | 0
Total | 0

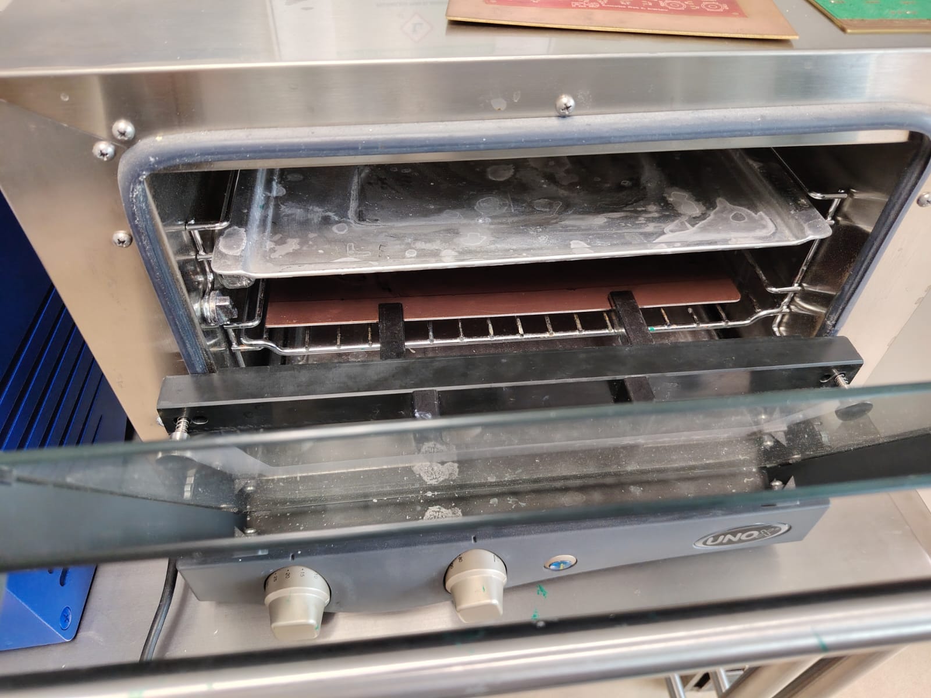
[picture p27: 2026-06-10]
docs/final report/Figures/making/7_fabricacion_horno_secado.jpeg

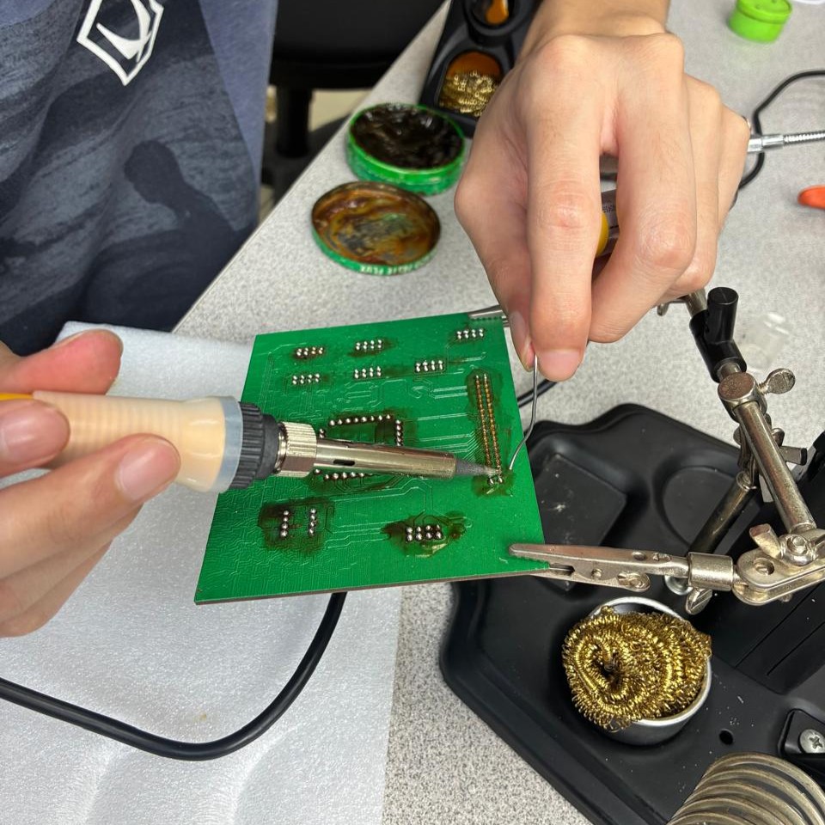
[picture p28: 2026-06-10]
docs/final report/Figures/making/20_soldadura_proceso.jpeg

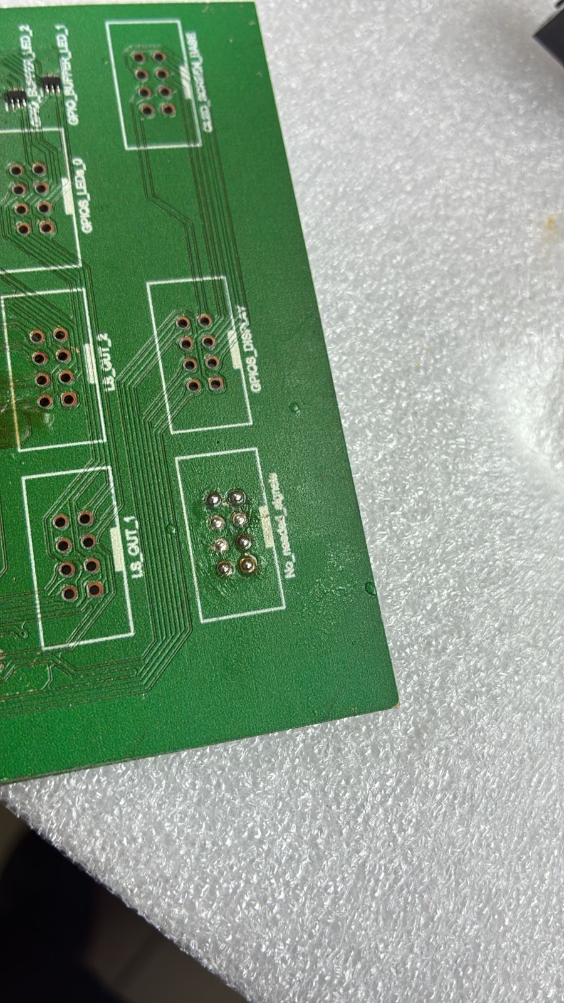
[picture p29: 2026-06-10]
docs/final report/Figures/making/17_soldadura.jpeg

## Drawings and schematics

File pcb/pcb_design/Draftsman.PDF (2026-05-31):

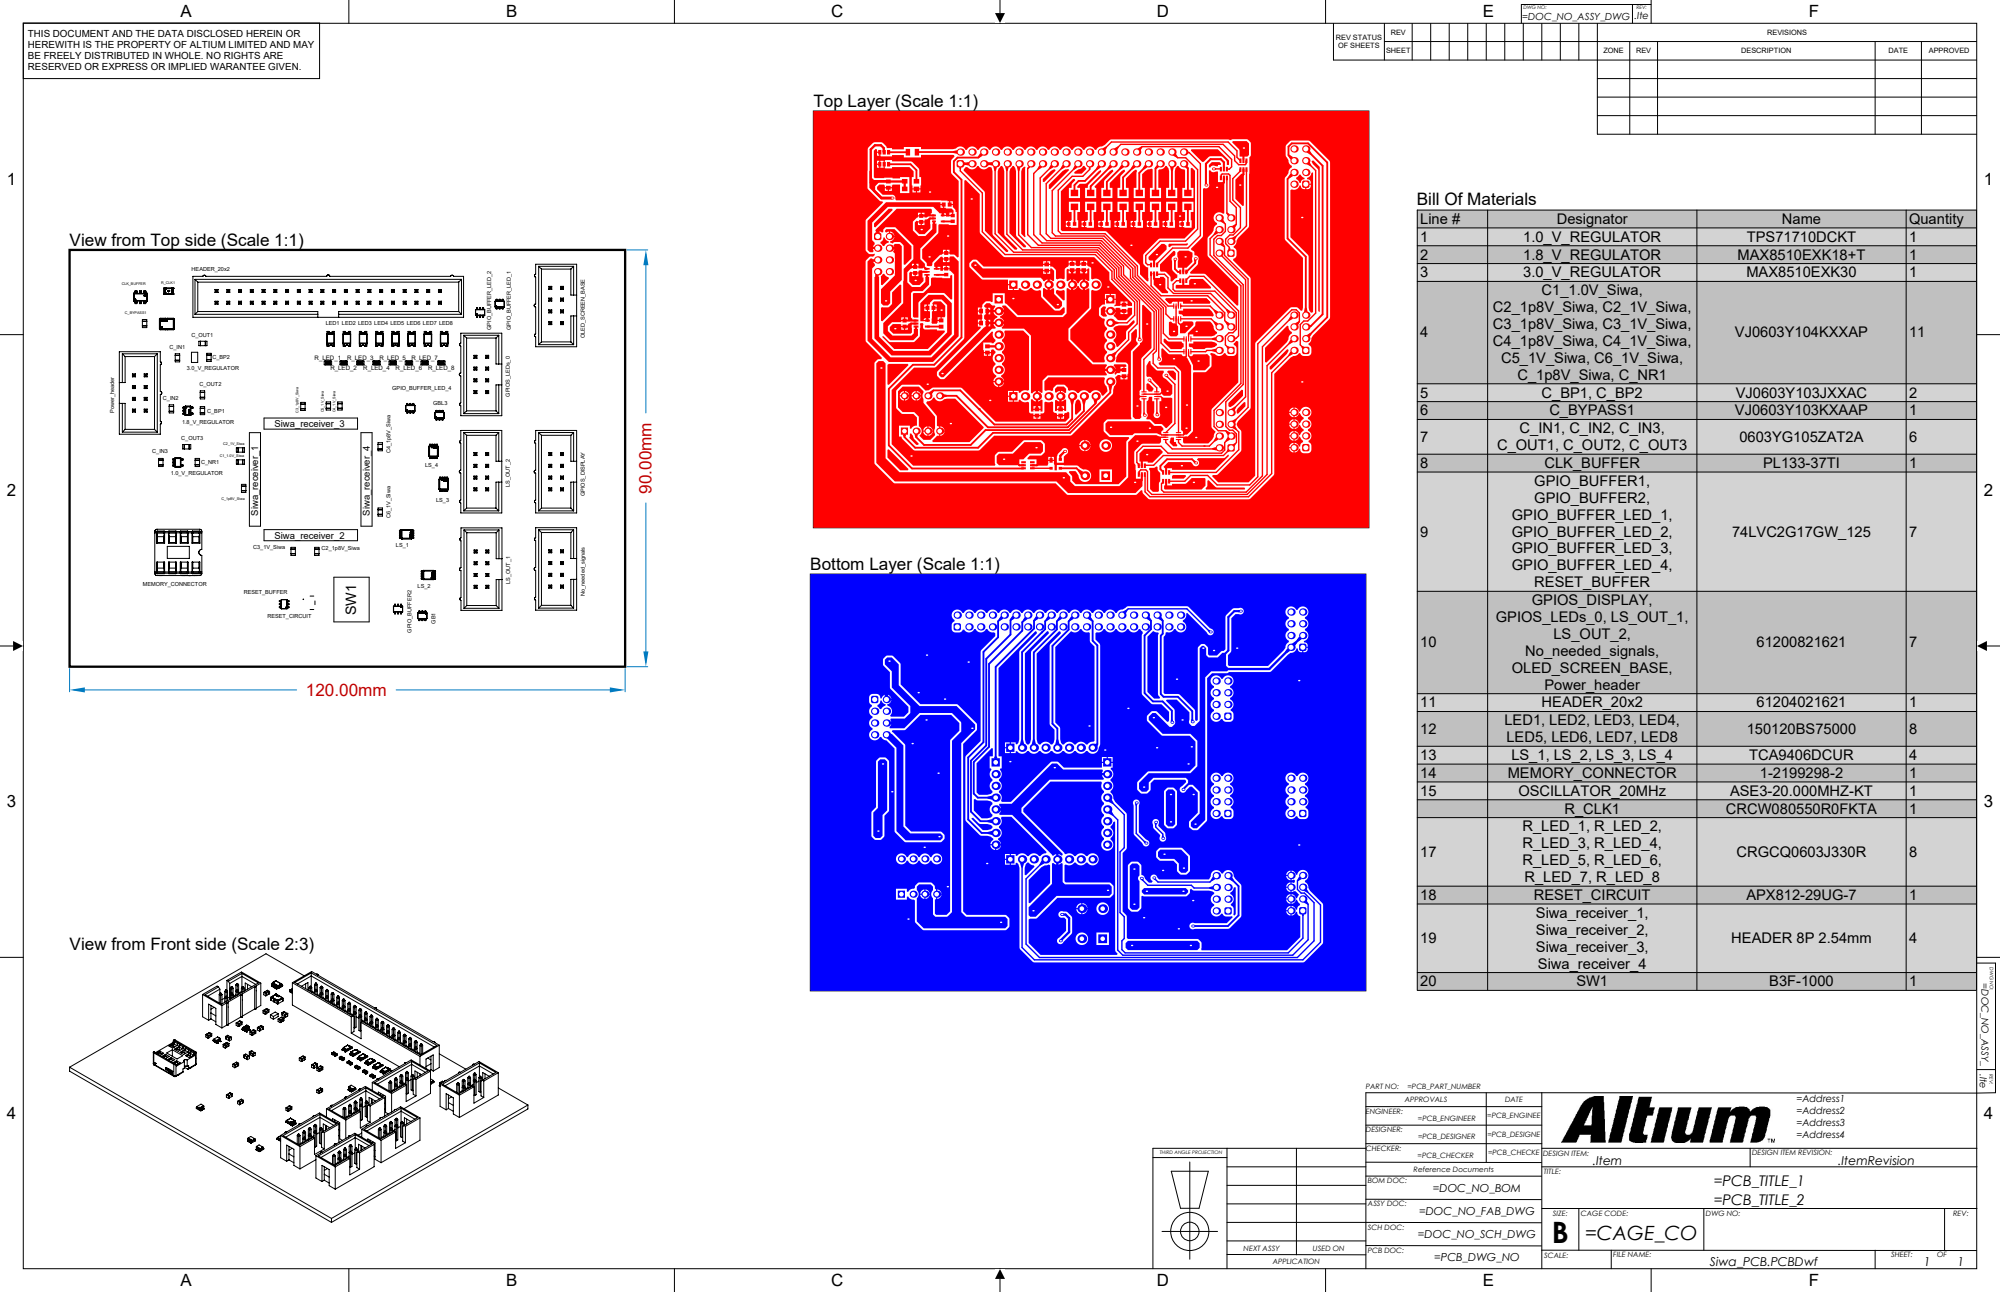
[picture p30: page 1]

HEREWITH IS THE PROPERTY OF ALTIUM LIMITED AND MAY
BE FREELY DISTRIBUTED IN WHOLE. NO RIGHTS ARE
RESERVED OR EXPRESS OR IMPLIED WARANTEE GIVEN.

Line # 123456789 | C1_1.0V_Siwa, C2_1p8V_Siwa, C2_1V_Siwa, C3_1p8V_Siwa, C3_1V_Siwa, C4_1p8V_Siwa, C4_1V_Siwa, C5_1V_Siwa, C6_1V_Siwa, C_1p8V_Siwa, C_NR1 | VJ0603Y104KXXAP

1.0_V_REGULATOR | TPS71710DCKT | Quantity 111
Designator | Name

View from Top side (Scale 1:1)

1.8_V_REGULATOR | MAX8510EXK18+T
3.0_V_REGULATOR | MAX8510EXK30

GPIO_BUFFER1, GPIO_BUFFER2, GPIO_BUFFER_LED_1, GPIO_BUFFER_LED_2, GPIO_BUFFER_LED_3, GPIO_BUFFER_LED_4, RESET_BUFFER | 74LVC2G17GW_125 | 112161771841118141

R_LED_2

C_BP1, C_BP2 | VJ0603Y103JXXAC
C_BYPASS1 | VJ0603Y103KXAAP

CLK_BUFFER | PL133-37TI

10 | GPIOS_DISPLAY, GPIOS_LEDs_0, LS_OUT_1, LS_OUT_2, No_needed_signals, OLED_SCREEN_BASE, Power_header | 61200821621

11 | HEADER_20x2 | 61204021621
12 | LED1, LED2, LED3, LED4, LED5, LED6, LED7, LED8 | 150120BS75000

13 | LS_1, LS_2, LS_3, LS_4 | TCA9406DCUR
14 | MEMORY_CONNECTOR | 1-2199298-2
15 | OSCILLATOR_20MHz | ASE3-20.000MHZ-KT

R_CLK1 | CRCW080550R0FKTA

17 | R_LED_1, R_LED_2, R_LED_3, R_LED_4, R_LED_5, R_LED_6, R_LED_7, R_LED_8 | CRGCQ0603J330R

18 | RESET_CIRCUIT | APX812-29UG-7
19 | Siwa_receiver_1, Siwa_receiver_2, Siwa_receiver_3, Siwa_receiver_4 | HEADER 8P 2.54mm | .It

View from Front side (Scale 2:3)

APPROVALS | DATE

ENGINEER: =PCB_ENGINEER | =PCB_ENGINEE

DESIGNER: =PCB_DESIGNER | =PCB_DESIGNE

THIRD ANGLE PROJECTION

CHECKER: =PCB_CHECKER | =PCB_CHECKE

SIZE: | CAGE CODE: B =CAGE_CO

SCH DOC: =DOC_NO_SCH_DWG

NEXT ASSY | USED ON

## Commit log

2026-03-22 datasheets and schematics
    [61200821621.SchDoc, ASE3-20.000MHz-K-T.SchDoc, PL133-37.SchDoc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]
2026-03-22 Corresponding Datasheets and Schematics
    [150120BS75000.SchDoc, 61204021621.SchDoc, 74LVC2G17GW_125.PcbLib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]
2026-03-23 Datasheets and Schematics Documents
    [1-2199298-2.SchDoc, APX812-29UG7.PcbLib, APX812-29UG7.SchDoc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]
2026-03-24 Schematics and datasheets
    [B3F-1000S.PcbLib, B3F-1000S.SchDoc, B3F-1000S.SchLib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]
2026-04-06 complete schematic
    [Siwa_PCB.SchDoc]
2026-04-06 component libraries needed for the complete schematic
    [74LVC2G17GW_125.PcbLib, 74LVC2G17GW_125.SchLib, APX812-29UG7.PcbLib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]
2026-04-16 Complete schematic update
    [Siwa_PCB.SchDoc]
2026-04-25 Schematic update and PCB design
    [Siwa_PCB.PcbDoc, Siwa_PCB.SchDoc]
2026-04-25 Changed folder of PCB
    [Siwa_PCB.PcbDoc]
2026-04-25 Added an extra 1.8V trace
    [Siwa_PCB.PcbDoc]
2026-05-09 Updated PCB, added PCB Drawing and all Altium files of the PCB
    [74LVC2G17GW_125.PcbLib, 74LVC2G17GW_125.SchLib, APX812-29UG7.PcbLib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]
2026-06-17 Se agrega figuras de diseño y PDF final, cambio en .gitignore
